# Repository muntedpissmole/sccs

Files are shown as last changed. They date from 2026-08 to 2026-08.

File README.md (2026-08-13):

<h1>
  SCCS
  The Singularity Camper Control System
</h1>

The SCCS is a control system for the electrics in your caravan or camper trailer. It replaces a switch panel and battery/water gauges etc. with a modern touchscreen UI that provides:
- Automated control of lighting based on sunset/sunrise times and door/panel open and closes.
- Display of important information:
  - Battery level and usage
  - Solar generation
  - Water tank levels
  - Location data
  - outside/fridge temperature and weather forecasts
  - Sonos speakers

The system is made up of a Raspberry Pi and custom PCB, the SCCS Core that is the central hub where all field wiring connects to.

The SCCS software configures the Raspberry Pi as a router so that Internet can be distributed from a USB/Wi-Fi hotspot or Starlink through a downstream WAP, enabling a local Wi-Fi network that gives your devices access to the UI and provides ad-filtered Internet access.

Networking services - NAT, DNS, DHCP and ad-filtering are provided by nftables and Pi-Hole, which are automatically configured during installation. Instructions are provided for installing the UniFi OS server for management of UniFi WAP points if desired. Apple HomeKit and Google Home can be configured to enable voice commands of lighting through Siri or Gemini. Cloudflare Tunnels is supported for remote access to the system while away from the caravan/camper.

An interactive demo is available at [demo.singularityautomation.com.au](https://demo.singularityautomation.com.au).

## Getting started

## Quickstart

1. Order SCCS Core PCB from JLCPCB by uploading the contents of the `/kicad/production` folder to JLCPCB. Get PCBA (assembly) done as well - you will receive a warning during the component placement stage that the same component is mapped to multiple parts. This is intentional, tick the checkboxes to include them in the build and continue.
2. Install wiring and SCCS core.
3. Install the software with the install command:

```bash
curl -fsSL https://raw.githubusercontent.com/muntedpissmole/sccs/main/install.sh -o /tmp/sccs-install.sh && sudo bash /tmp/sccs-install.sh
```

Full instructions are in the [project wiki](https://github.com/muntedpissmole/sccs/wiki/).

## System overview

A touchscreen in the kitchen or similar area shows the main user interface and is also reachable from phones or tablets on the LAN:

- Dimmable lighting sliders with red/white anti-bug mode and on/off buttons for non-dimmable loads (water, lighting, fridge circuits)
- Ambient lights that fade on as it gets dark
- One-touch lighting scenes
- Control of Sonos speakers
- Light/dark UI themes and an extensive settings page
- Integration with Apple HomeKit and Google Home

## Display of Environmental information

- Water tank level
- Current temperature and fridge/freezer temperatures
- Current battery charge, voltage, current consumption, estimated power remaining and current/daily solar generation
- GPS coordinates, closest suburb, altitude, satellite quality, sunrise/sunset, and the day/evening/night timing that drives automation
- 4 Day weather forecast, humidity and expected overnight temperature if Internet is present
- Internet connection quality details
- What lights are on and what doors or panels are open
- Health status of connected hardware modules like solar or GPS

## Hardware architecture

- Raspberry Pi 4/5
- Dual ESP32-S3s for 16 channels of PWM dimming via MOSFETs
- u-blox NEO-M9N GPS for location data
- Victron SmartShunt and SmartSolar support for battery and solar monitoring
- WS281X addressable LED strip outputs
- 10A relays for non-dimmable loads like lighting circuits, floodlights and water pumps
- Reed switch inputs for door/panel sensing and triggering of lights
- 1-Wire bus for temperature sensors
- Water tank level sensor input
- Spare channels for everything for expansion

## Hardware and User Interface

### SCCS Core

<table>
  <tr>
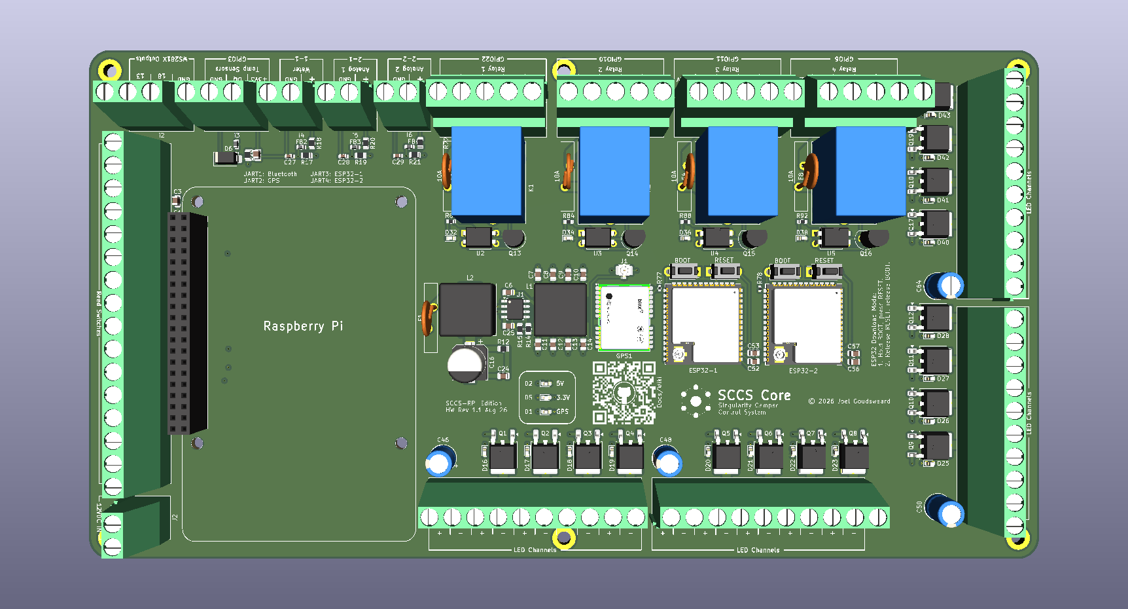
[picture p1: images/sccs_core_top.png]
SCCS Core — top, bare board
    <td align="center" width="50%"></td>
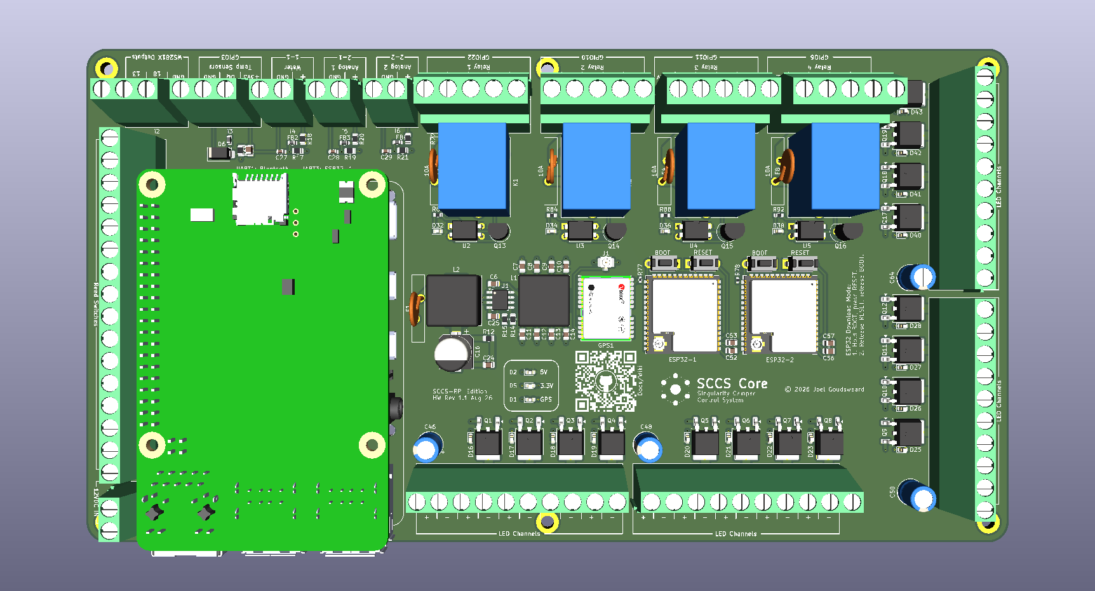
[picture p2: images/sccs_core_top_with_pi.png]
SCCS Core — top, with Raspberry Pi fitted
    <td align="center" width="50%"></td>
  </tr>
  <tr>
    <td align="center"><strong>Top (bare board)</strong></td>
    <td align="center"><strong>Top (with Raspberry Pi fitted)</strong></td>
  </tr>
  <tr>
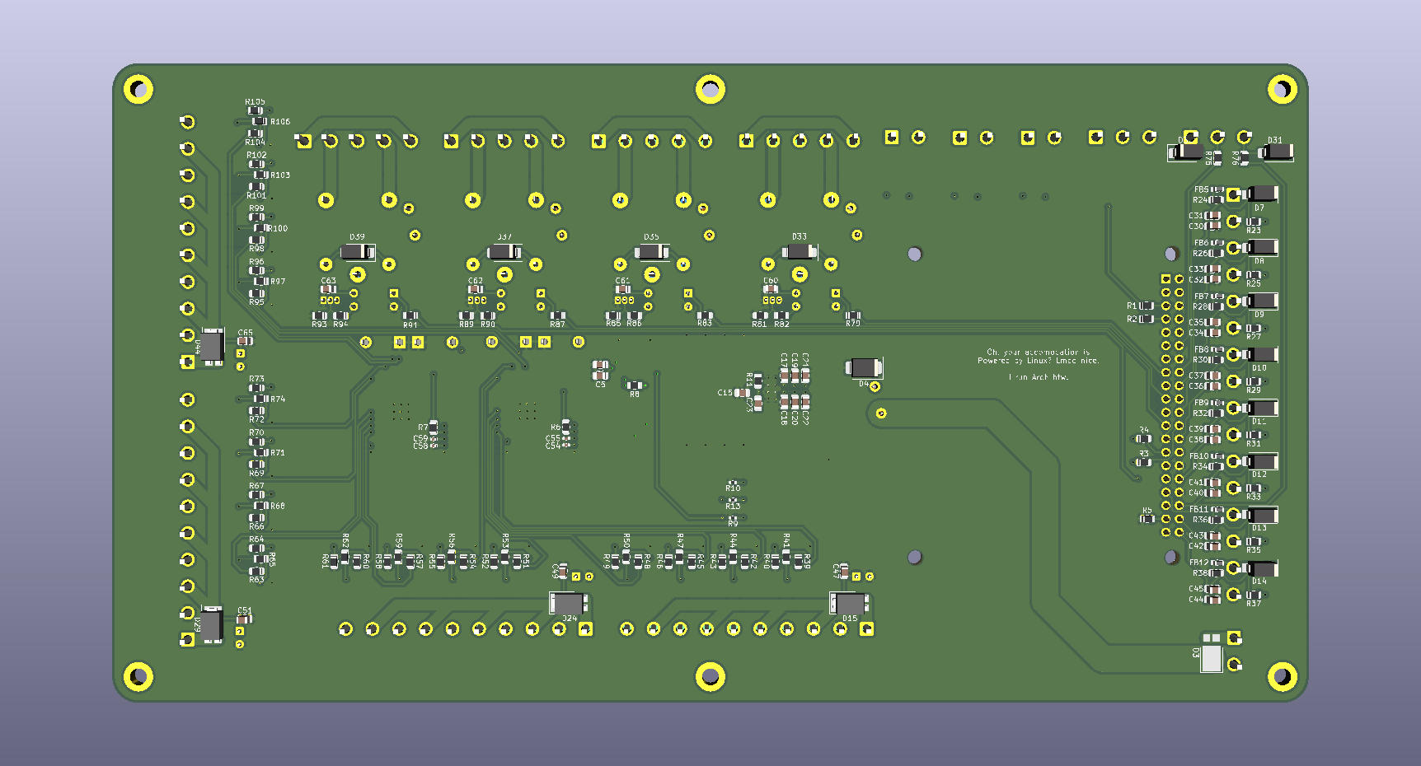
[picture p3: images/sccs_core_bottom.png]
SCCS Core — bottom
    <td align="center"></td>
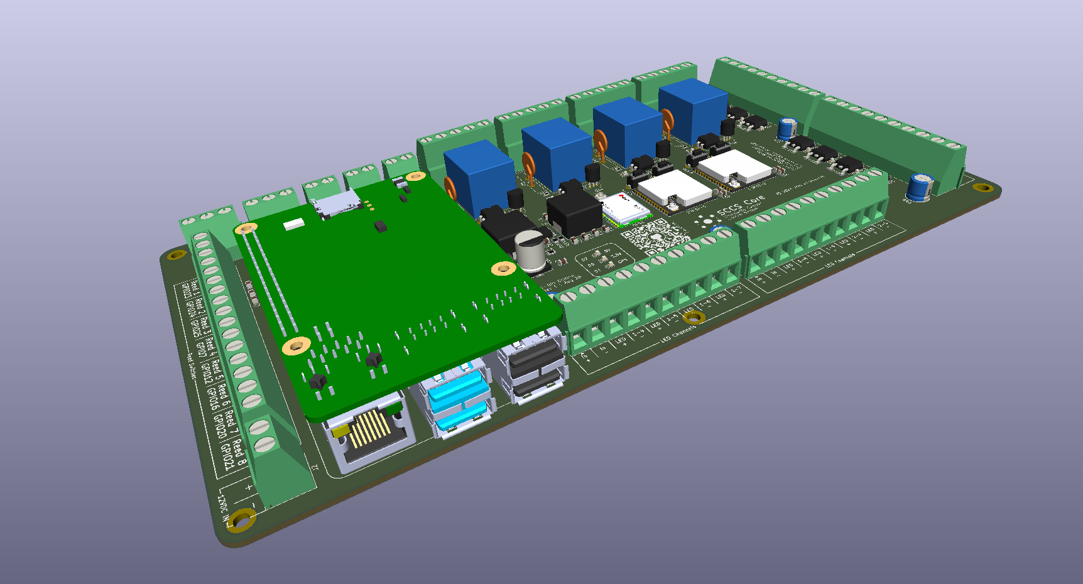
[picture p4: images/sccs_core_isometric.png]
SCCS Core — isometric view with Raspberry Pi fitted
    <td align="center"></td>
  </tr>
  <tr>
    <td align="center"><strong>Bottom</strong></td>
    <td align="center"><strong>Isometric (with Raspberry Pi fitted)</strong></td>
  </tr>
</table>

### 3D Printable Mount

<table>
  <tr>
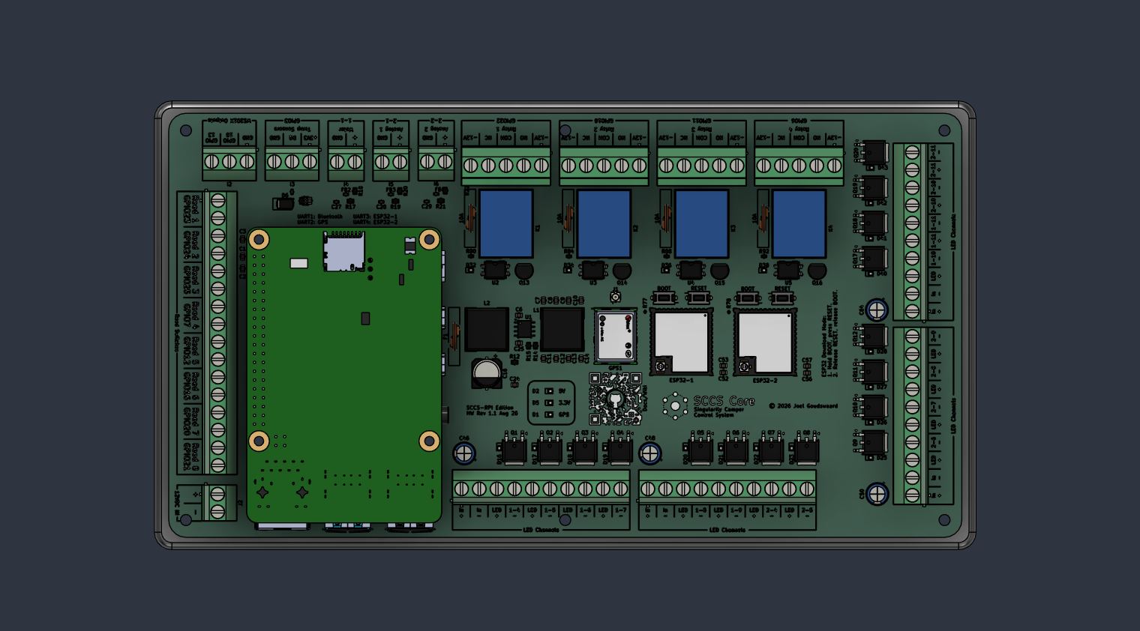
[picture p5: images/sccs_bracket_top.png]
SCCS Core — 3D printable frame, top
    <td align="center" width="50%"></td>
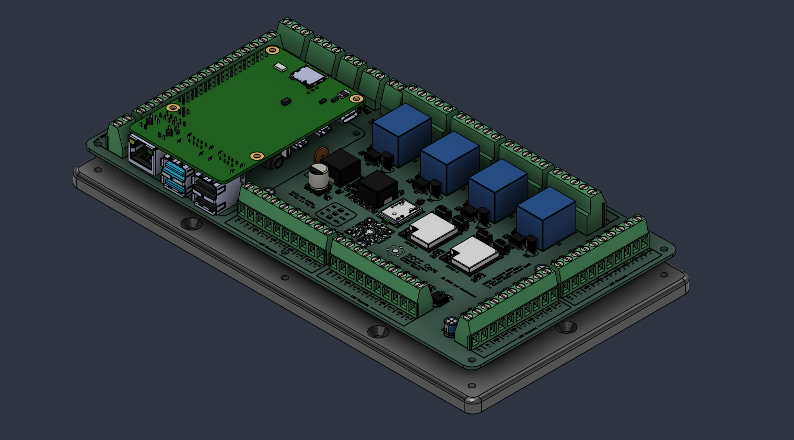
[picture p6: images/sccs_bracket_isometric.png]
SCCS Core — 3D printable frame, isometric
    <td align="center" width="50%"></td>
  </tr>
  <tr>
    <td align="center"><strong>3D printable frame (top)</strong></td>
    <td align="center"><strong>3D printable frame (isometric)</strong></td>
  </tr>
</table>

### User Interface

<table>
  <tr>
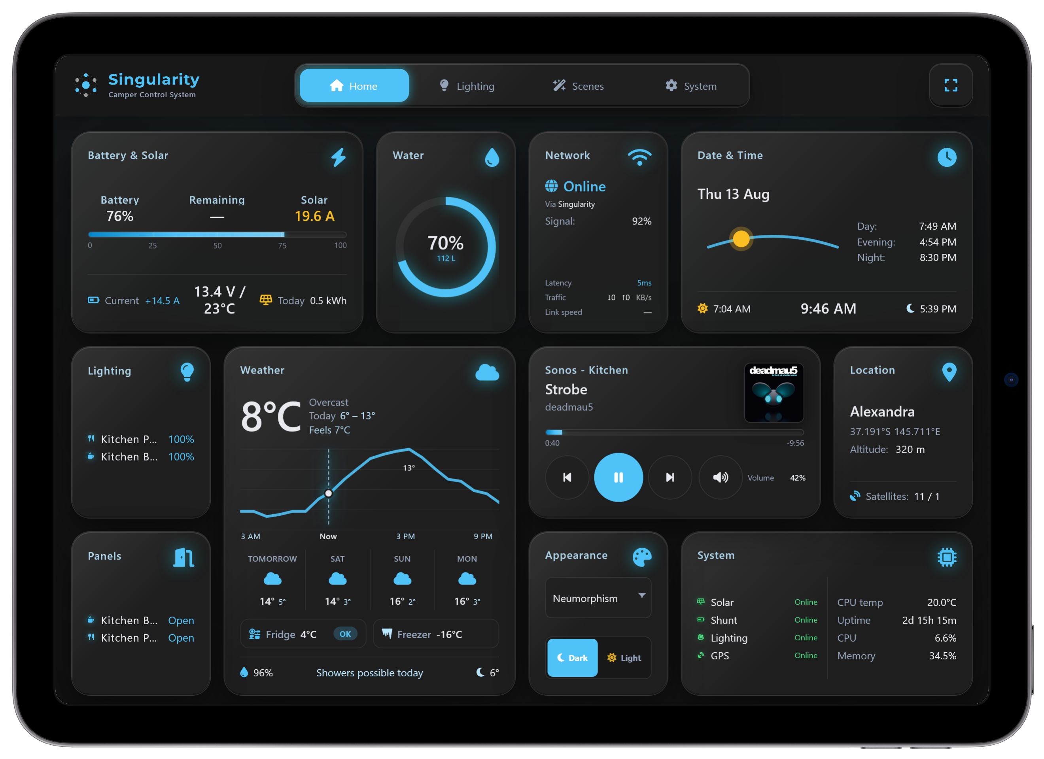
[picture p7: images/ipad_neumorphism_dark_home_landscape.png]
Neumorphism dark — iPad landscape
    <td align="center" width="50%"></td>
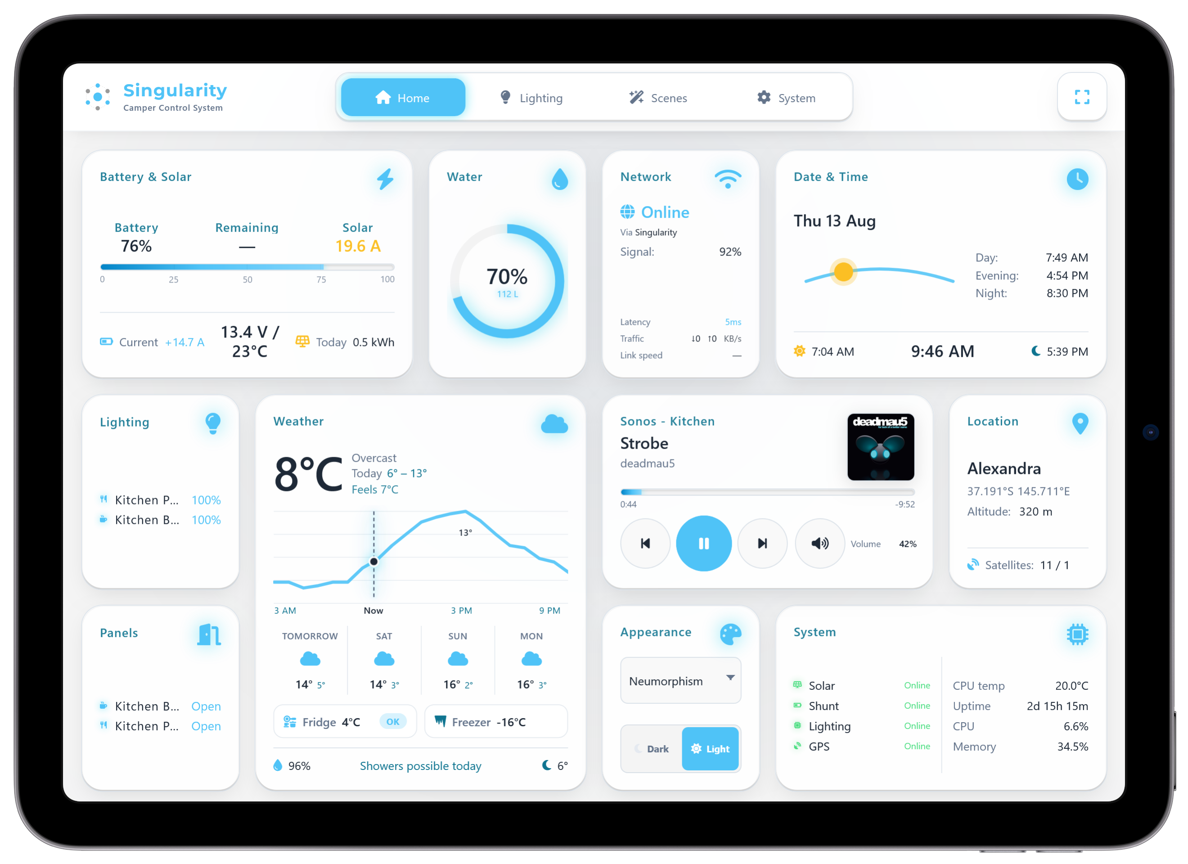
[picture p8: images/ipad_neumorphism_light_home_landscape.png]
Neumorphism light — iPad landscape
    <td align="center" width="50%"></td>
  </tr>
  <tr>
    <td align="center"><strong>Neumorphism (Dark) — iPad</strong></td>
    <td align="center"><strong>Neumorphism (Light) — iPad</strong></td>
  </tr>
  <tr>
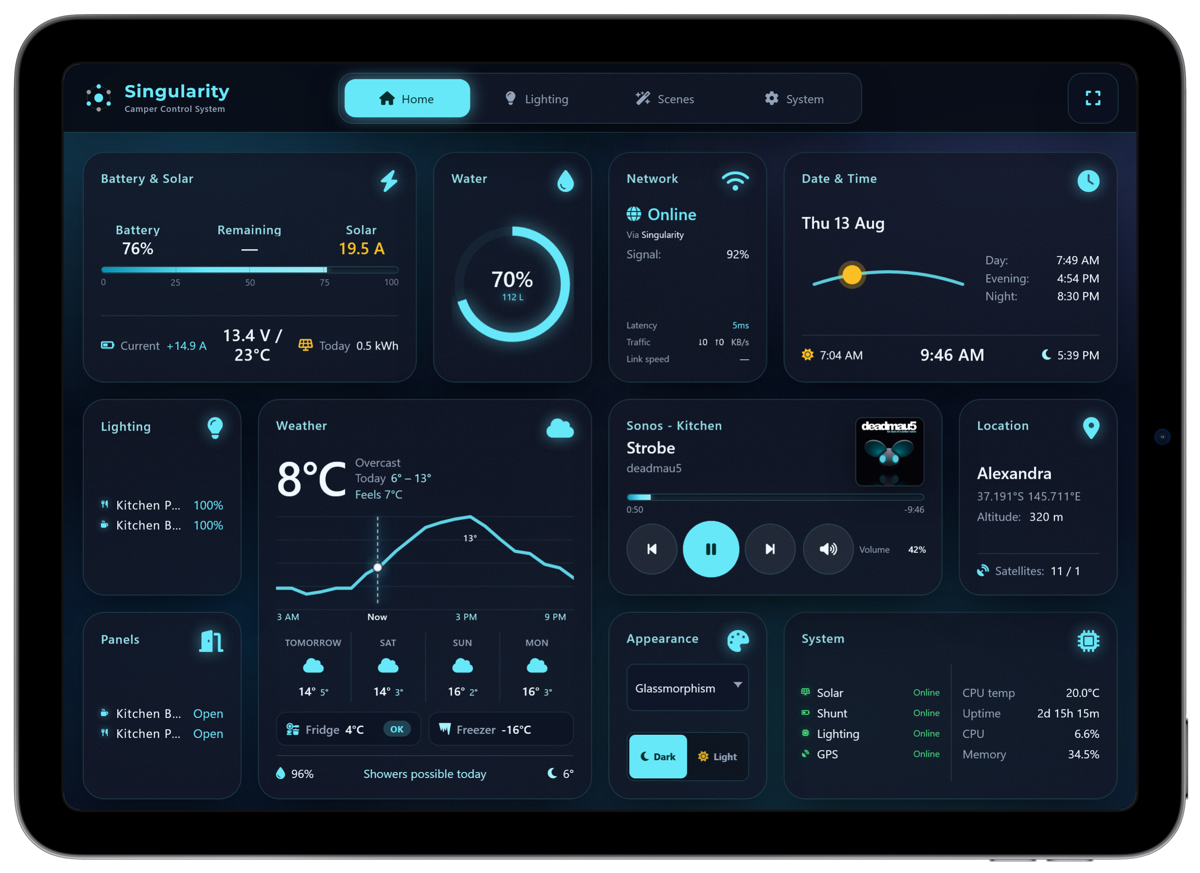
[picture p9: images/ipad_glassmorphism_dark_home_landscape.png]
Glassmorphism dark — iPad landscape
    <td align="center"></td>
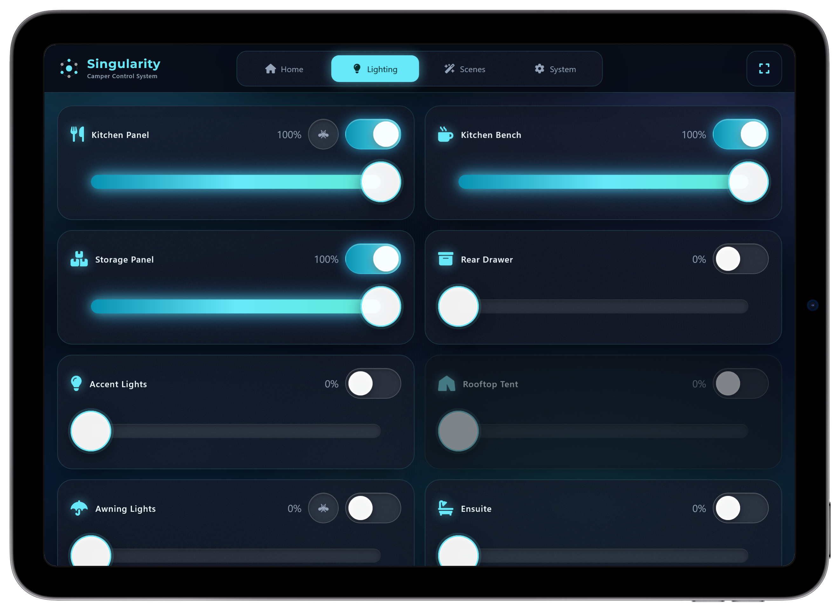
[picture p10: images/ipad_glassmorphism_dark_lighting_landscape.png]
Glassmorphism dark — iPad lighting
    <td align="center"></td>
  </tr>
  <tr>
    <td align="center"><strong>Glassmorphism (Dark) — iPad</strong></td>
    <td align="center"><strong>Glassmorphism (Dark) — iPad Lighting</strong></td>
  </tr>
  <tr>
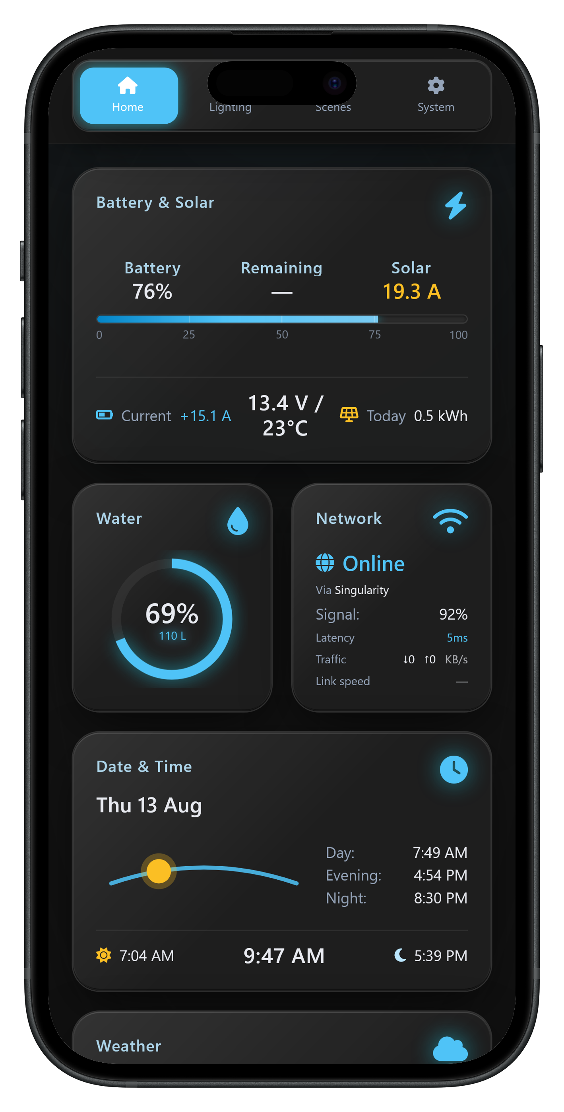
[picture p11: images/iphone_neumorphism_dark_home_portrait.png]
Neumorphism dark — iPhone portrait
    <td align="center"></td>
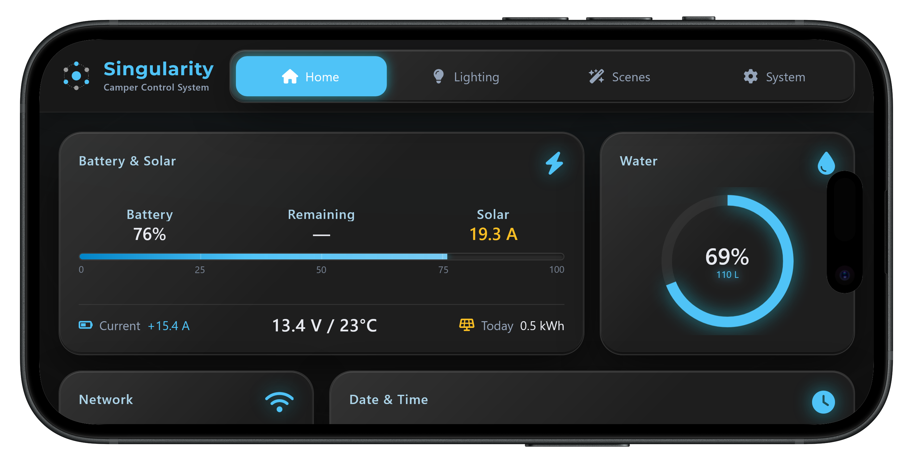
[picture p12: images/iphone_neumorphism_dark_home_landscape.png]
Neumorphism dark — iPhone landscape
    <td align="center"></td>
  </tr>
  <tr>
    <td align="center"><strong>Neumorphism (Dark) — iPhone Portrait</strong></td>
    <td align="center"><strong>Neumorphism (Dark) — iPhone Landscape</strong></td>
  </tr>
</table>

---

## Documentation

Wiring, installation, configuration, and optional packages are on the **[project wiki](https://github.com/muntedpissmole/sccs/wiki)** (start at [Home](https://github.com/muntedpissmole/sccs/wiki/Home) for the setup path and glossary).

| Topic | Wiki page |
|---|---|
| Overview, setup path, glossary | [Home](https://github.com/muntedpissmole/sccs/wiki/Home) |
| Shopping list and wiring | [Wiring and Hardware](https://github.com/muntedpissmole/sccs/wiki/Wiring-and-Hardware) |
| Imaging the Pi and installer | [Software Installation](https://github.com/muntedpissmole/sccs/wiki/Software-Installation) |
| `sccs.conf`, phases, lights, sensors | [Software Configuration](https://github.com/muntedpissmole/sccs/wiki/Software-Configuration) |
| SmartShunt / SmartSolar Bluetooth | [Victron Setup](https://github.com/muntedpissmole/sccs/wiki/Victron-Setup) |
| Apple Home app / Siri (optional) | [HomeKit](https://github.com/muntedpissmole/sccs/wiki/HomeKit) |
| Google Home / Gemini (optional) | [Google Home](https://github.com/muntedpissmole/sccs/wiki/Google-Home) |
| LAN, NAT, Pi-hole, USB internet | [Networking](https://github.com/muntedpissmole/sccs/wiki/Networking) |
| UniFi controller (optional) | [UniFi OS Server](https://github.com/muntedpissmole/sccs/wiki/UniFi-OS-Server) |

---

## License

Licensed under the [MIT License](LICENSE).

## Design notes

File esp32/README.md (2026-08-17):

# SCCS ESP32-S3 firmware

ESP32-S3-WROOM-1U firmware for the two lighting/analog MCUs.

Host protocol (UART0, 115200 8N1): `SET` / `RAMP` / `GET` / `ANALOG` / `GETVCC` / `GETALL`.

Same UART as the ROM bootloader, so `BOOT`+`RESET` uploads over the Pi host serial port.

| Sketch | Role | Pi UART | ESP host UART | PWM GPIOs | Analog GPIOs |
|---|---|---|---|---|---|
| `esp32_1/` | ESP32-1 | `/dev/ttyAMA2` (Pi GPIO 4/5) | GPIO 44 RX / 43 TX (U0) | 4–11 | 1 (water) |
| `esp32_2/` | ESP32-2 | `/dev/ttyAMA3` (Pi GPIO 8/9) | GPIO 44 RX / 43 TX (U0) | 4–11 | 1, 2 |

Shared core: `SccsEspFirmware.h` (copied into each sketch folder).

## Build / flash

- Chip: **ESP32-S3** / **ESP32-S3-WROOM-1U**
- Upload over the Pi host UART (U0). Stop `sccs` first so the port is free.
- Hold BOOT, tap RESET, release BOOT, then upload. Tap RESET again to run.

```bash
arduino-cli core update-index
arduino-cli core install esp32:esp32

arduino-cli compile --fqbn esp32:esp32:esp32s3 esp32/esp32_1
arduino-cli upload -p /dev/ttyAMA2 --fqbn esp32:esp32:esp32s3 esp32/esp32_1

arduino-cli compile --fqbn esp32:esp32:esp32s3 esp32/esp32_2
arduino-cli upload -p /dev/ttyAMA3 --fqbn esp32:esp32:esp32s3 esp32/esp32_2
```

## ADC / water level

- 12-bit reads (0–4095), 64-sample average — matches `water_adc_max = 4095` on the Pi
- `GETVCC` returns `3300` (mV of the 3V3 rail for the 150 Ω pull-ups)
- Water sender on ESP32-1 GPIO 1: empty ~240 Ω, full ~33 Ω (`config/sccs.conf` `[sensors]`)

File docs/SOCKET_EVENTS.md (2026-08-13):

# SCCS Socket Event Contract

This document defines every Socket.IO event used by the lighting backend in this pass.

## Offline overlay

When Socket.IO disconnects (or fails to load), `#offline-overlay` appears after 800ms and blocks interaction until reconnect. Implemented in `offline-overlay.js` + `socket-client.js`.

## Client → Server

### `light_change`

User moved a dimmer slider or toggled a dimmer pill.

```json
{ "name": "kitchen_bench", "brightness": 65 }
```

RGB bug lights include mode:

```json
{ "name": "kitchen_panel", "brightness": 55, "mode": "red" }
```

- `name` must be in `compiled.light_names`
- `brightness` clamped 0–100 server-side
- `mode` only applied for RGB lights

**HTTP fallback:** `POST /api/light` with the same JSON body.

### `relay_change`

User toggled a relay control (socket only — no HTTP fallback).

```json
{ "name": "floodlights", "on": true }
```

Relays use `expires: manual` — they persist through scenes, reed changes, and phase changes until toggled again.

### `get_reeds`

Request effective reed states. Server replies with `reed_update`.

### `set_scene`

Activate a lighting scene (one-shot reconcile with ramp).

```json
{ "scene": "bedtime" }
```

**HTTP fallback:** `POST /api/scene` with the same JSON body.

### `force_phase`

Lock or clear phase override.

```json
{ "phase": "Evening" }
```

Clear: `{ "phase": null }`

### `force_reed`

Diagnostics override (also affects main UI effective states).

```json
{ "name": "rooftop_tent", "closed": true }
```

Clear force: `{ "name": "rooftop_tent", "closed": null }`

## Server → Client

### `lights_config`

Sent on `connect`. Ordered list of UI controls from `sccs.conf`:

```json
[
  { "name": "rooftop_tent", "label": "Rooftop Tent", "type": "dimmer", "icon": "fa-tent", "has_mode": false, "order": 10 }
]
```

`type` is `dimmer` or `relay`.

### `state_update`

Authoritative light/relay levels after reconcile.

```json
{
  "kitchen_bench": 65,
  "kitchen_panel": 55,
  "kitchen_panel_mode": "white",
  "floodlights": 1
}
```

- Dimmers: 0–100 integer brightness
- Relays: truthy/falsey on state
- RGB lights: `{name}_mode` key with `white` or `red`

### `reeds_config`

Sent on `connect`. Reed metadata for the system tile:

```json
[{ "name": "kitchen_panel", "label": "Kitchen Panel", "icon": "fa-utensils", "order": 10 }]
```

### `reed_update` (main UI)

Effective reed states — hardware merged with operator forces.

```json
{ "states": { "rooftop_tent": true, "kitchen_bench": false } }
```

`true` = closed (secure), `false` = open.

**Main UI rule:** clients must not guess forced vs raw. Use this event only.

### `reed_diag_update` (diagnostics — future tile)

Raw hardware + force metadata. Not consumed by the lighting tab yet.

```json
{
  "states": { "rooftop_tent": true },
  "forced": { "kitchen_bench": false }
}
```

### `phase_update` (main UI)

```json
{ "phase": "evening", "day_start": "06:12", "evening_start": "18:45", "night_start": "21:30" }
```

### `gps_update`

Full GPS telemetry from `modules/gps` (also drives home location tile).

```json
{
  "fix_quality": 2,
  "satellites": 9,
  "latitude": -37.191,
  "longitude": 145.711,
  "suburb": "Alexandra",
  "hardware_missing": false
}
```

### `sensor_update`

Water tank and 1-wire temperatures.

```json
{
  "water_percent": 68,
  "outside_temp_c": 12.4,
  "fridge_temp_c": null,
  "temp_valid": true
}
```

### `set_gps_simulation`

Diagnostics: force no-fix mode.

```json
{ "no_fix": true }
```

### `phase_diag_update` (diagnostics)

```json
{ "forced": false }
```

`forced: true` when operator has locked phase via diag controls.

## REST

| Route | Purpose |
|---|---|
| `POST /api/light` | HTTP fallback for `light_change` |
| `GET /api/scenes` | Scene list for Scenes tab |
| `POST /api/scene` | HTTP fallback for `set_scene` |
| `GET /api/reeds` | Reed labels/icons for system tile |
| `GET /api/explain` | Policy snapshot: sources, desired vs observed, drift |

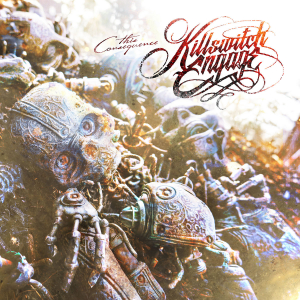
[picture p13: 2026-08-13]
static/images/kse-this-consequence.jpg

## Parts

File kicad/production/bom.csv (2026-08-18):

Designator | Footprint | Quantity | Value | LCSC Part #
C1, C17 | 0805 | 2 | 10uF | C15850
C10, C11, C12, C13, C14, C19, C20, C21, C22, C3, C4, C46, C50, C7, C8, C9 | 0805 | 16 | 22uF | C86816
C15 | 0805 | 1 | 2.7nF | C113859
C16 | CP_Elec_8x10 | 1 | 220uF | C165536
C18, C2, C26, C31, C33, C35, C37, C39, C41, C43, C45, C55, C57, C59, C61, C62, C63, C64, C65 | 0805 | 19 | 100nF | C49678
C23 | 0805 | 1 | 33pF | C541516
C24, C54, C56, C58, C60 | CP_Radial_D6.3mm_P2.50mm | 5 | 100uF | C44587
C25 | 0805 | 1 | 10nF | C237168
C27, C28, C29 | 0603 | 3 | 100nF | C1590
C30, C32, C34, C36, C38, C40, C42, C44 | 0805 | 8 | 1uF | C91185
C47, C5, C51, C6 | 0805 | 4 | 0.1uF | C86041
C48, C49, C52, C53 | 0402 | 4 | 100nF | C60474
D1 | 0603 | 1 | GPS | C2286
D10, D11, D12, D13, D14, D6, D7, D8, D9 | D_SMA | 9 | SMAJ3.3CA | C18199545
D15, D16, D17, D18, D3 | D_PowerDI-5 | 5 | ~ | C2759901
D19, D22, D23, D24, D25, D26, D27, D30, D31, D32, D33, D34 | 0603 | 12 | White | C2290
D2 | 0603 | 1 | 5V | C2286
D20, D28 | 0603 | 2 | Red | C2286
D21, D29 | 0603 | 2 | Green | C12065
D35, D36 | D_SMA | 2 | SMAJ5.0CA | C78402
D37, D39, D41, D43 | 0603 | 4 | Blue | C2288
D38, D40, D42, D44 | D_SMA | 4 | 1N4007 | C64915
D4 | D_SMB | 1 | SMAJ18A/TR13 | C571369
D5 | 0603 | 1 | 3.3V | C2286
ESP32-1, ESP32-2 | ESP32-S3-WROOM-1U | 2 | ESP32-S3-WROOM-1 | C3013946
F1, F2, F3, F4, F5 | Fuse_Bourns_MF-RG1000 | 5 | 10A | C14767
FB1, FB10, FB11, FB12, FB2, FB3, FB4, FB5, FB6, FB7, FB8, FB9 | 0603 | 12 | FerriteBead | C1002
GPS1 | ublox_NEO | 1 | NEO-M9N-00B | C5119087
I1 | TerminalBlock_Phoenix_MKDS-1,5-16-5.08_1x16_P5.08mm_Horizontal | 1 | Reed Switches | C508906
I2 | TerminalBlock_Phoenix_MKDS-1,5-3-5.08_1x03_P5.08mm_Horizontal | 1 | WS281X Outputs | C8412
I3 | TerminalBlock_Phoenix_MKDS-1,5-3-5.08_1x03_P5.08mm_Horizontal | 1 | Temp Sensors | C8412
I4 | TerminalBlock_Phoenix_MKDS-1,5-2-5.08_1x02_P5.08mm_Horizontal | 1 | Water | C8445
I5 | TerminalBlock_Phoenix_MKDS-1,5-2-5.08_1x02_P5.08mm_Horizontal | 1 | Analog 1 | C8445
I6 | TerminalBlock_Phoenix_MKDS-1,5-2-5.08_1x02_P5.08mm_Horizontal | 1 | Analog 2 | C8445
J1 | SMA_Amphenol_132134-11_Vertical | 1 | Conn_Coaxial | C20415804
J2 | TerminalBlock_Phoenix_MKDS-1,5-2-5.08_1x02_P5.08mm_Horizontal | 1 | 12VDC IN | C8445
K1, K2, K3, K4 | Relay_SPDT_SANYOU_SRD_Series_Form_C | 4 | Relay_SPDT | C35449
L1, L2 | L_SXN_SMDRI127 | 2 | 3.3uH | C24550
PI1 | PinSocket_2x20_P2.54mm_Vertical | 1 | Raspberry PI HAT | C132132
PWM1, PWM2, PWM3, PWM4 | TerminalBlock_Phoenix_MKDS-1,5-10-5.08_1x10_P5.08mm_Horizontal | 4 | LED Channels | C29173
Q1, Q10, Q11, Q12, Q13, Q14, Q15, Q16, Q2, Q3, Q4, Q5, Q6, Q7, Q8, Q9 | TO-252-2 | 16 | IRLB8721PBF | C99124
Q17, Q18, Q19, Q20 | TO-92_Inline | 4 | 2N7000 | C9114
R1, R2, R21, R23, R25, R27, R29, R3, R31, R33, R35, R4, R6, R7, R8 | 0805 | 15 | 220R | C17557
R10, R13, R9 | 0402 | 3 | 1K | C11702
R100, R104, R41, R44, R47, R50, R53, R56, R59, R62, R65, R68, R71, R74, R77, R80, R83, R86, R92, R96 | 0805 | 20 | 10K | C17414
R101, R105, R40, R43, R46, R49, R52, R55, R58, R61, R64, R67, R70, R73, R76, R79, R82, R85, R93, R97 | 0805 | 20 | 100R | C17408
R102, R90, R94, R98 | 0805 | 4 | 330R | C17630
R103, R91, R95, R99 | 0603 | 4 | 1K | C5123612
R11 | 0805 | 1 | 15.8K | C17468
R12 | 0805 | 1 | 1R | C25271
R14 | 0805 | 1 | 115K | C158272
R15 | 0805 | 1 | 22.1K | C17552
R16 | 0805 | 1 | 2.2K | C17520
R17, R18, R19 | 0805 | 3 | 150R | C17471
R20, R22, R24, R26, R28, R30, R32, R34, R5 | 0805 | 9 | 4.7K | C17673
R36, R37, R38, R39 | 0402 | 4 | 10K | C60490
R42, R45, R48, R51, R54, R57, R60, R63, R66, R69, R72, R75, R78, R81, R84, R87 | 0805 | 16 | 1K | C17513
R88, R89 | 0805 | 2 | 33R | C17634
RE1 | TerminalBlock_Phoenix_MKDS-3-5-5.08_1x05_P5.08mm_Horizontal | 1 | Relay 1 | C8423
RE2 | TerminalBlock_Phoenix_MKDS-3-5-5.08_1x05_P5.08mm_Horizontal | 1 | Relay 2 | C8423
RE3 | TerminalBlock_Phoenix_MKDS-3-5-5.08_1x05_P5.08mm_Horizontal | 1 | Relay 3 | C8423
RE4 | TerminalBlock_Phoenix_MKDS-3-5-5.08_1x05_P5.08mm_Horizontal | 1 | Relay 4 | C8423
RP? | raspberrypi_4 | 1 | Raspberry_Pi_2_3
SW1, SW3 | SW_PUSH_1P1T_6x3.5mm_H5.0_APEM_MJTP1250 | 2 | RESET | C500070
SW2, SW4 | SW_PUSH_1P1T_6x3.5mm_H5.0_APEM_MJTP1250 | 2 | BOOT | C500070
U1 | SOIC-8-1EP_3.9x4.9mm_P1.27mm_EP2.95x4.9mm_Mask2.71x3.4mm_ThermalVias | 1 | AP64501SP-13 | C2071517
U2, U3, U4, U5 | DIP-4_W7.62mm | 4 | PC817 | C5353

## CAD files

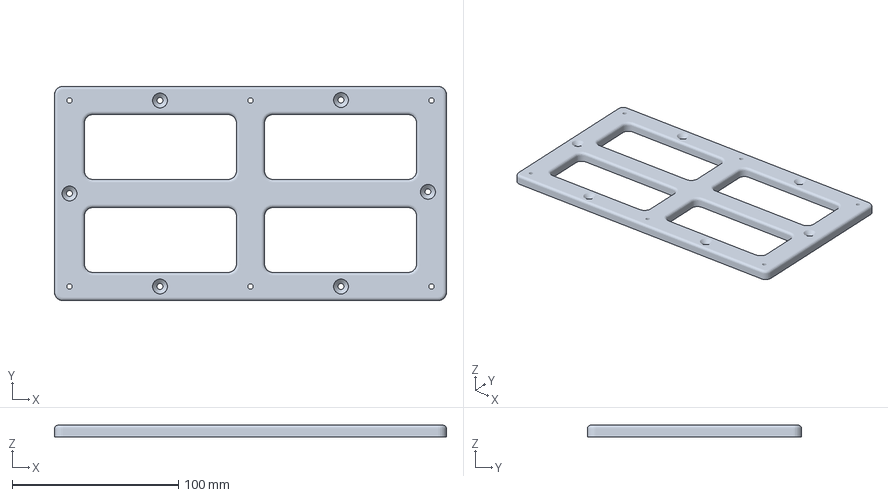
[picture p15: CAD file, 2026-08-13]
kicad/SCCS Mount.3mf
236.1 x 129.0 x 7.00 mm

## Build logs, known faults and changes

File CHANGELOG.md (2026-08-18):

# Changelog

All notable changes to SCCS are documented in this file.

## [1.1.2.18082026] - 2026-08-18

### Added
- Installer 1-Wire setup can delete a temperature sensor role from `sccs.conf`; skip still leaves the existing value

## [1.1.1.18082026] - 2026-08-18

### Fixed
- Startup treated every reed as closed until the poller started, so the first lighting pass and a connecting UI could show “all panels closed”. Reeds are now sampled (three quick GPIO reads) before HTTP is advertised and before any lights or scenes run
- No-fix GPS sentences were stored as 0°N 0°E. Weather then fetched the equator (~24 °C). Empty GGA/RMC is ignored; with no valid fix the Alexandra fallback is used
- pynmea2 raised on void RMC datetime (`$GNRMC,,V,…`); those sentences no longer crash the GPS reader
- Settings tiles with `[hidden]` still painted in WebKit because author `display:flex` beat the UA rule

### Changed
- `[reeds]` comments map i1 pin pairs to functions; kitchen bench is GPIO23 and kitchen panel GPIO24
- Night bathroom scene renamed from `ensuite` to `bathroom`

## [1.1.17082026] - 2026-08-17

### Fixed
- ESP32 lighting stayed offline after a successful flash: the host protocol now uses UART0 (`Serial0` on GPIO 44/43), the same pins as the ROM bootloader, instead of a second `HardwareSerial(0)` on UART1
- Installer flashed over `/dev/ttyACM*` instead of the SCCS Core host UARTs; uploads now target `/dev/ttyAMA2` (ESP32-1) and `/dev/ttyAMA3` (ESP32-2) as the same user that compiled
- A failed `GETVCC` check after upload sent the installer back through the ESP32-1 flash loop. Handshake retries no longer re-flash; the next module is offered after a warning
- `USBMode=default` selected TinyUSB OTG (not the board default) and could hang `setup()` on modules with no USB. The FQBN stays `esp32:esp32:esp32s3`
- Pi UART has no RTS reset line, so esptool cannot start the app. The installer now asks for a RESET tap and checks `GETVCC` before moving on
- `sccs.service` is stopped for the upload and started again when the ESP step ends (including skip, abort, or Ctrl-C)
- Host `GETVCC` probe retries briefly after open so lighting can come online while firmware is still leaving reset

### Changed
- Installer enables the correct UART overlays per board: `uart2`/`uart3`/`uart4` on Pi 4, `uart1-pi5`/`uart2-pi5`/`uart3-pi5` on Pi 5 (GPS `/dev/ttyAMA1`, ESP1 `/dev/ttyAMA2`, ESP2 `/dev/ttyAMA3`)
- Firmware answers the host on a non-blocking line reader and prints `SCCS n READY` as soon as UART0 is up

## [1.0.0.13082026] - 2026-08-13

### Added
- Initial release of the Singularity Camper Control System (SCCS)
- Touchscreen UI for dimmable lighting, scenes, reeds, phases, water, climate, power, GPS, weather and networking
- Optional Apple HomeKit and Google Home control (off by default; installer menu 10 or Settings)
- Installer for imaging, Victron, LAN/Pi-hole, USB tethering and touchscreens

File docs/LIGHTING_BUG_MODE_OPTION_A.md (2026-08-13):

# Lighting bug mode — Option A (separate chip)

**Date:** 2026-06-11  
**Status:** Applied

## Problem

On `rgb_bug` lights (e.g. Kitchen Panel, Awning), the header toggle pill toggled **white ↔ bug (red) mode**, not on/off. Other cards use the same pill for **power**. Same control, different meaning.

## Solution (Option A)

- **Toggle pill** — on/off only (brightness 0 ↔ last brightness), same as PWM dimmers. Still uses `.bug-mode` styling (red) when bug mode is active.
- **Bug mode chip** — new mosquito button left of the pill; toggles `white` ↔ `red` mode only.
- **Slider / card chrome** — still turns red in bug mode (unchanged).

## Files changed

| File | Change |
|---|---|
| `static/js/lighting-controller.js` | Pill logic, `toggleBugMode()`, chip in card HTML, click handler |
| `static/css/components/lighting.css` | `.bug-mode-chip` styles |

## Behaviour before (revert target)

In `lighting-controller.js` → `updateLightUI()`:

```javascript
const pillOn = light.has_mode ? isBugMode : brightness > 0;
pills.forEach((pill) => {
    pill.classList.toggle('on', pillOn);
    pill.classList.toggle('bug-mode', isBugMode);
    ...
});
```

In `toggleControl()`:

```javascript
if (light.has_mode) {
    const newMode = currentMode === 'white' ? 'red' : 'white';
    // ... mode toggle only, no brightness change
    return;
}
```

Card HTML used `colour-toggle` class on the pill; no bug chip.

## How to revert

1. Delete `.bug-mode-chip` rules from `lighting.css`.
2. In `lighting-controller.js`:
   - Restore `pillOn = light.has_mode ? isBugMode : brightness > 0`.
   - Restore `bug-mode` class on pills in `updateLightUI()`.
   - Restore `if (light.has_mode) { ... mode toggle ... return; }` in `toggleControl()`.
   - Remove `toggleBugMode()` and bug-chip branch in `handleLightingClick`.
   - Remove bug chip from card HTML; restore `colour-toggle` on pill for `has_mode` lights.
3. Delete this doc if no longer needed.

## Unchanged

- Socket/API: `light_change` still sends `{ name, brightness, mode }`.
- Home tile bug indicator (`is-bug-mode` when `mode === 'red'`).
- Scenes / `*_mode` keys in state.
- Slider `.bug-mode` fill/thumb styling.

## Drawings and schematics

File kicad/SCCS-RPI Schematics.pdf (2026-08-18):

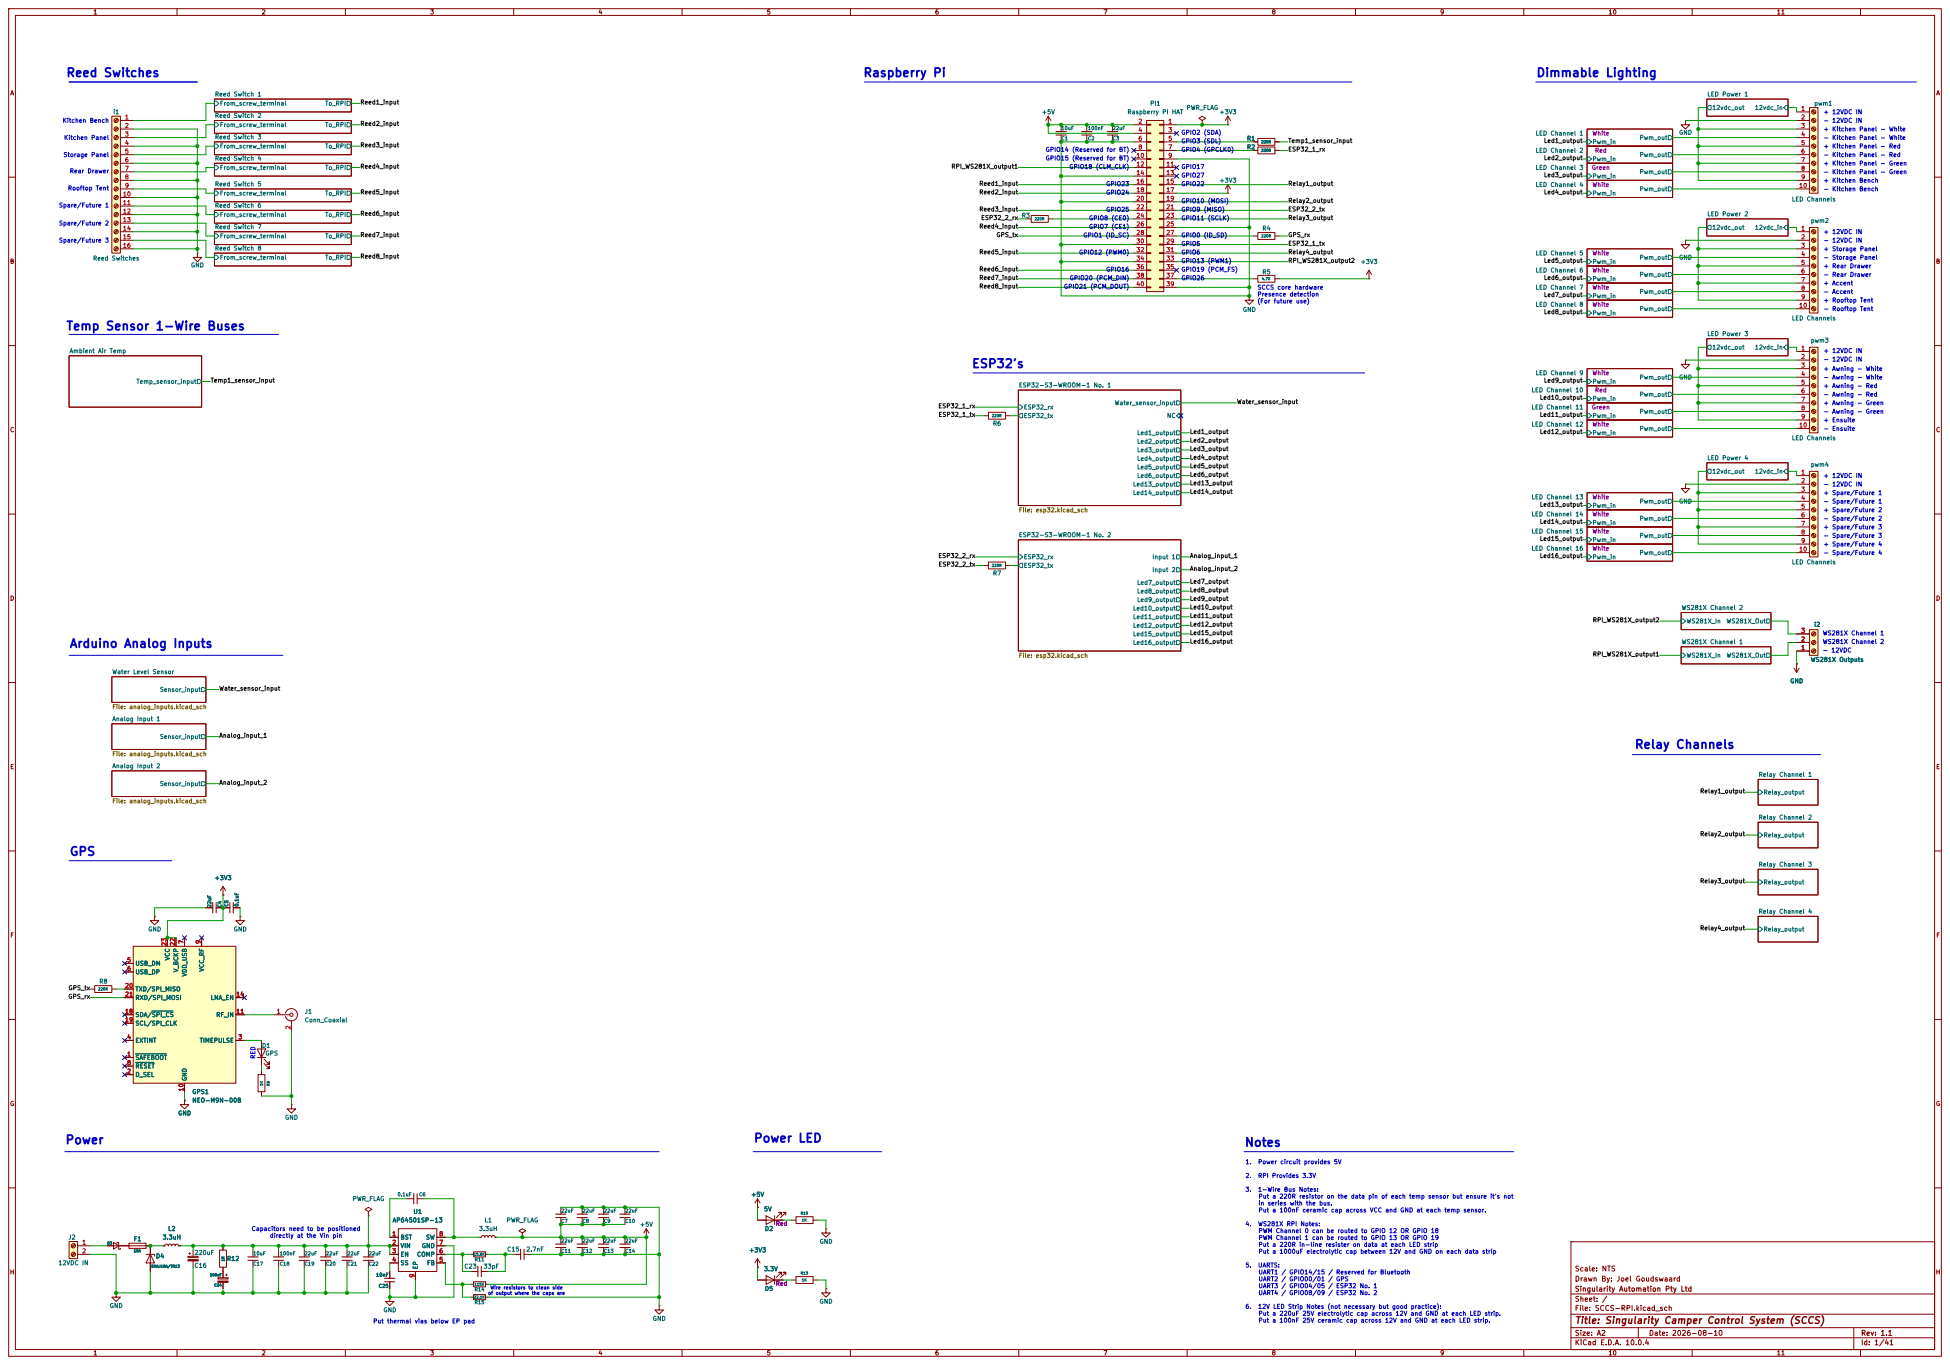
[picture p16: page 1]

Storage Panel Spare/Future 1

Spare/Future 3 Temp Sensor 1-Wire Buses

SCCS core hardware Presence detection

+ 12VDC IN + Ensuite - 12VDC IN - Awning - Green - Ensuite

+ Spare/Future 2 + Spare/Future 4

1. Power circuit provides 5V 2. RPI Provides 3.3V 3. 1-Wire Bus Notes: Put a 220R resistor on the data pin of each temp sensor but ensure it's not

in series with the bus. Put a 100nF ceramic cap across VCC and GND at each temp sensor. 4. WS281X RPI Notes: PWM Channel 0 can be routed to GPIO 12 OR GPIO 18 PWM Channel 1 can be routed to GPIO 13 OR GPIO 19 Put a 220R in-line resister on data at each LED strip Put a 1000uF electrolytic cap between 12V and GND on each data strip 5. UARTS: UART1 / GPIO14/15 / Reserved for Bluetooth UART2 / GPIO00/01 / GPS UART3 / GPIO04/05 / ESP32 No. 1 UART4 / GPIO08/09 / ESP32 No. 2

Capacitors need to be positioned
directly at the Vin pin

Scale: NTS
Drawn By: Joel Goudswaard
Singularity Automation Pty Ltd
Sheet: /
File: SCCS-RPI.kicad_sch
Title: Singularity Camper Control System (SCCS)

Wire resistors to clean side of output where the caps are

6. 12V LED Strip Notes (not necessary but good practice): Put a 220uF 25V electrolytic cap across 12V and GND at each LED strip. Put a 100nF 25V ceramic cap across 12V and GND at each LED strip.

Put thermal vias below EP pad

Size: A2 | Rev: 1.1
KiCad E.D.A. 10.0.4 | Id: 1/41

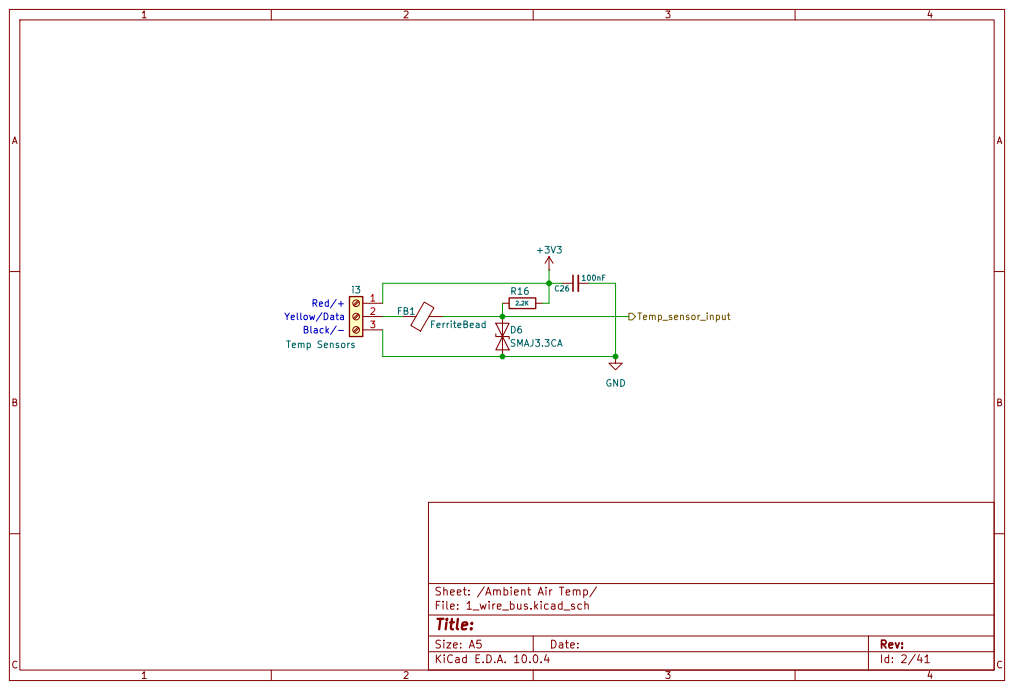
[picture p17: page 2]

Sheet: /Ambient Air Temp/
File: 1_wire_bus.kicad_sch
Title:

Size: A5 | Rev: | C Date:
KiCad E.D.A. 10.0.4 | Id: 2/41

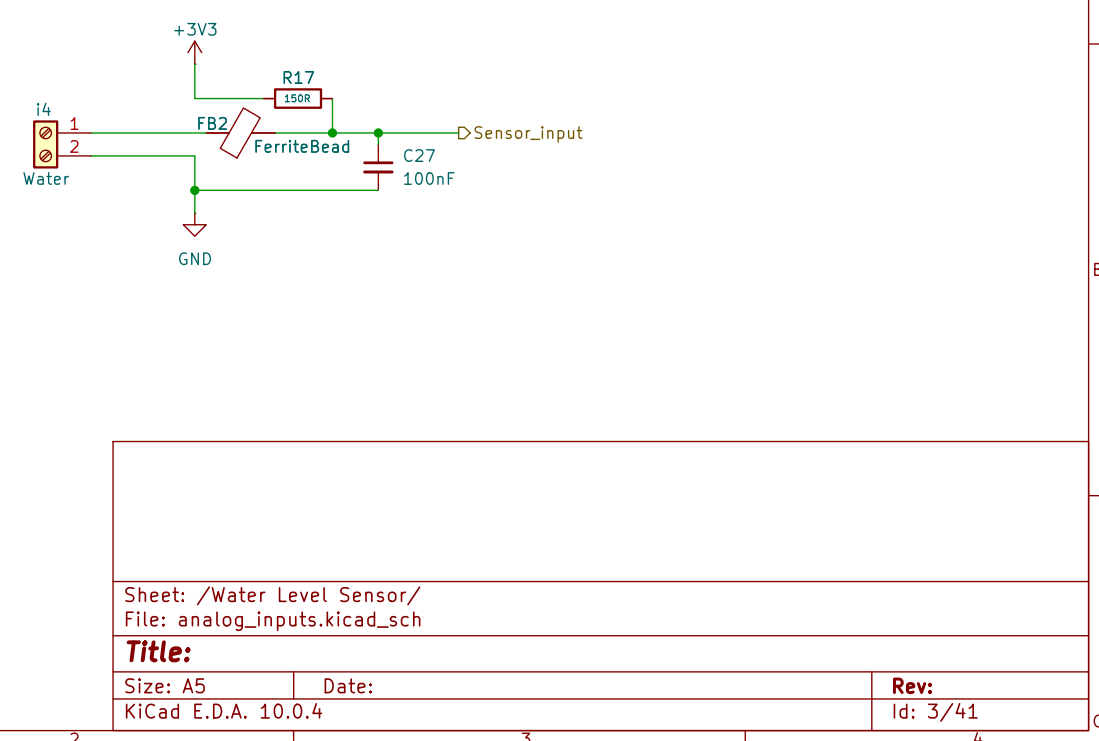
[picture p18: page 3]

Sheet: /Water Level Sensor/
File: analog_inputs.kicad_sch
Title:

Size: A5 | Rev: | C Date:
KiCad E.D.A. 10.0.4 | Id: 3/41

Size: A5 | Rev: | C Date:
KiCad E.D.A. 10.0.4 | Id: 4/41

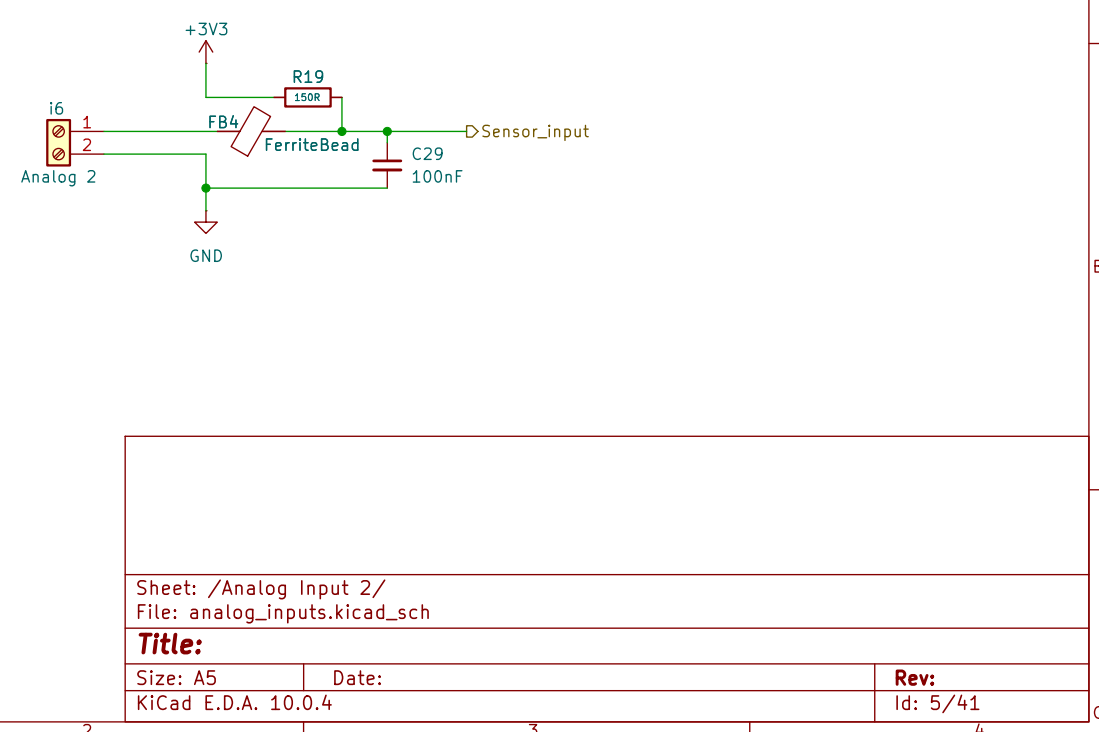
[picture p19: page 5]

Size: A5 | Rev: | C Date:
KiCad E.D.A. 10.0.4 | Id: 5/41

Size: A5 | Rev: | C Date:
KiCad E.D.A. 10.0.4 | Id: 6/41

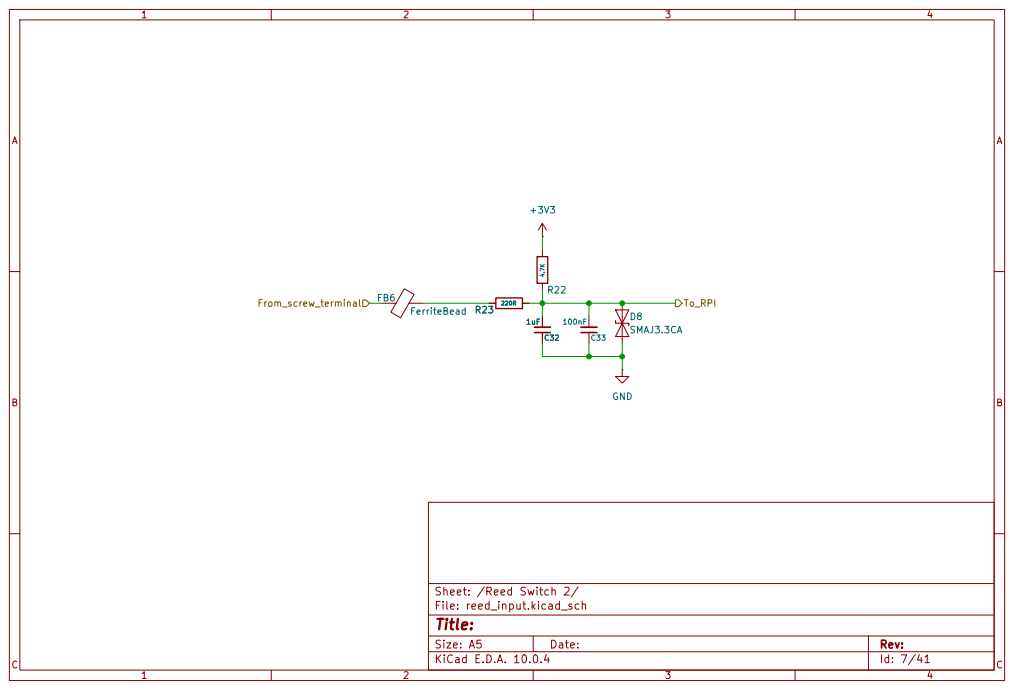
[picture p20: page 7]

Size: A5 | Rev: | C Date:
KiCad E.D.A. 10.0.4 | Id: 7/41

Size: A5 | Rev: | C Date:
KiCad E.D.A. 10.0.4 | Id: 8/41

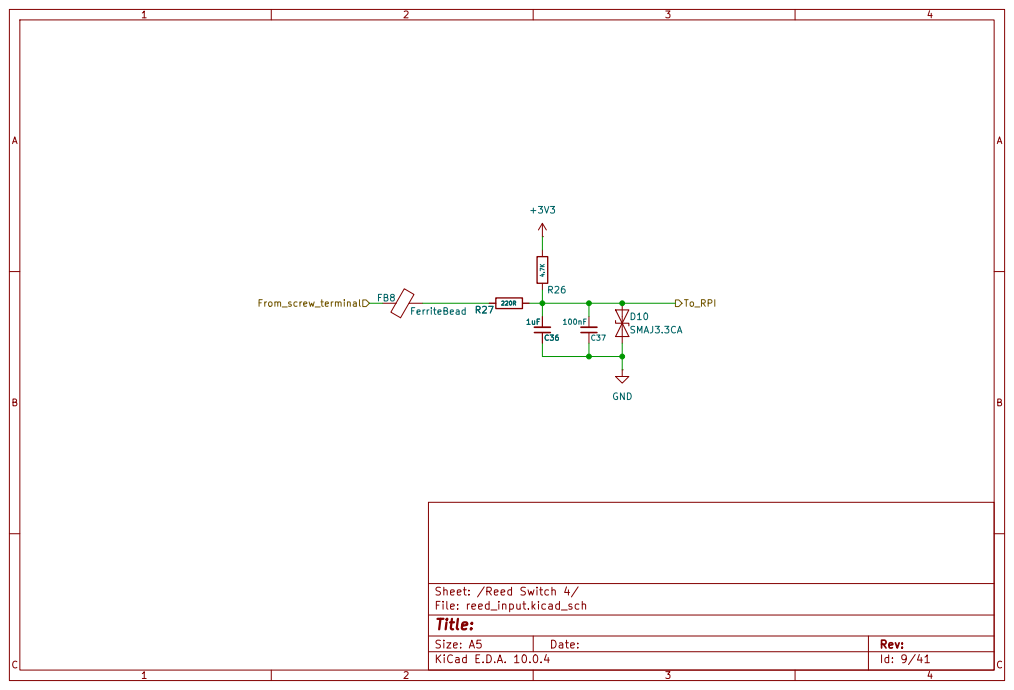
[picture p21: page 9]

Size: A5 | Rev: | C Date:
KiCad E.D.A. 10.0.4 | Id: 9/41

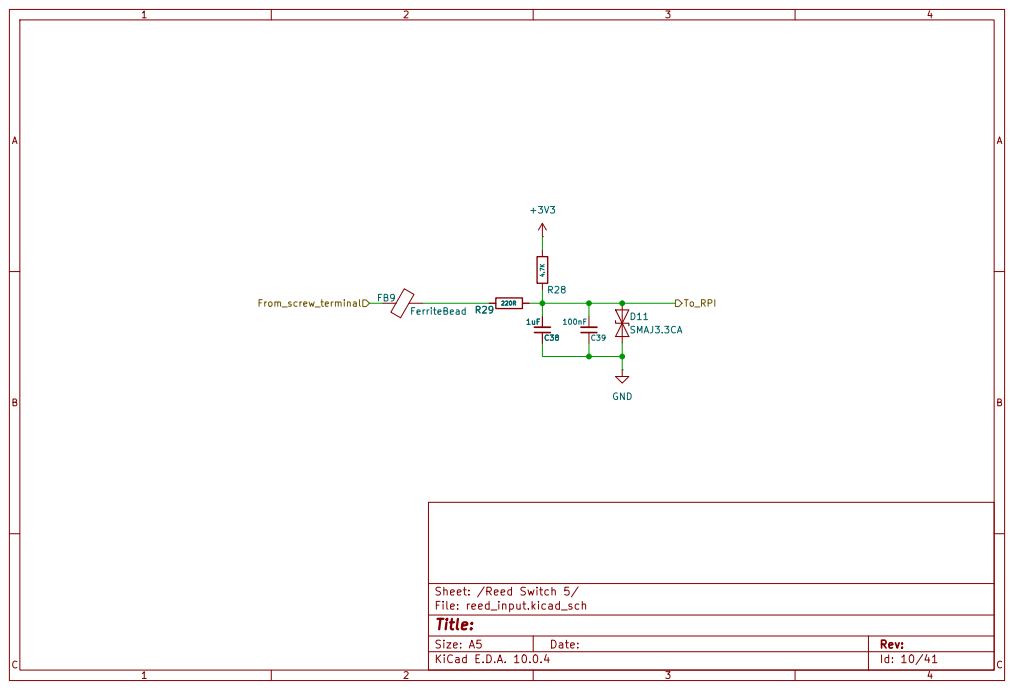
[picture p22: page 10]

Size: A5 | Rev: | C Date:
KiCad E.D.A. 10.0.4 | Id: 10/41

Size: A5 | Rev: | C Date:
KiCad E.D.A. 10.0.4 | Id: 11/41

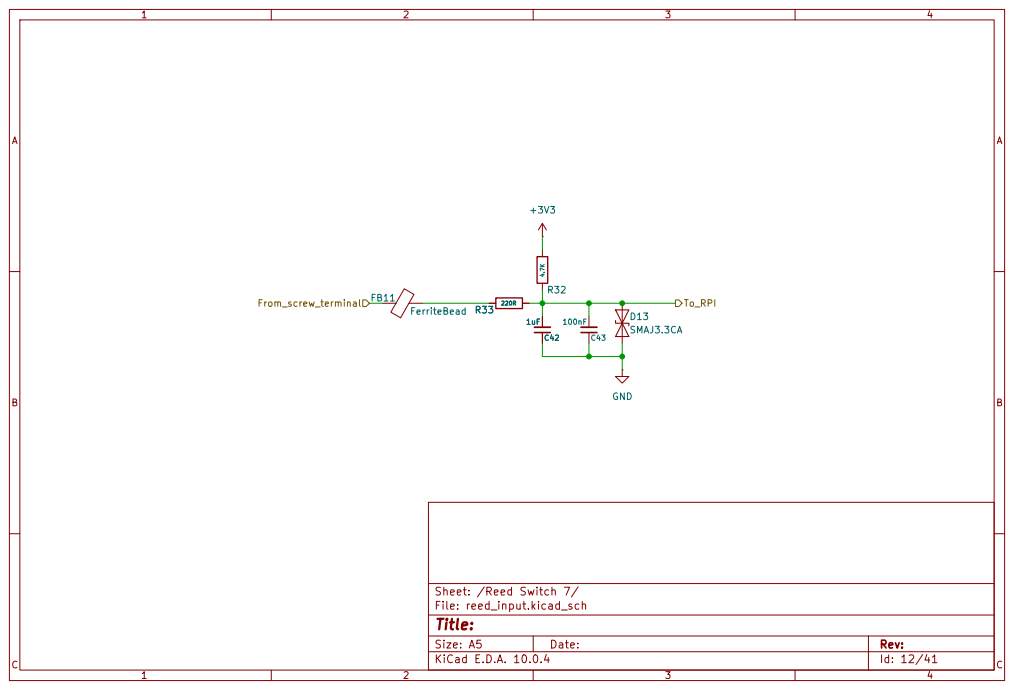
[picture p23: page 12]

Size: A5 | Rev: | C Date:
KiCad E.D.A. 10.0.4 | Id: 12/41

Size: A5 | Rev: | C Date:
KiCad E.D.A. 10.0.4 | Id: 13/41

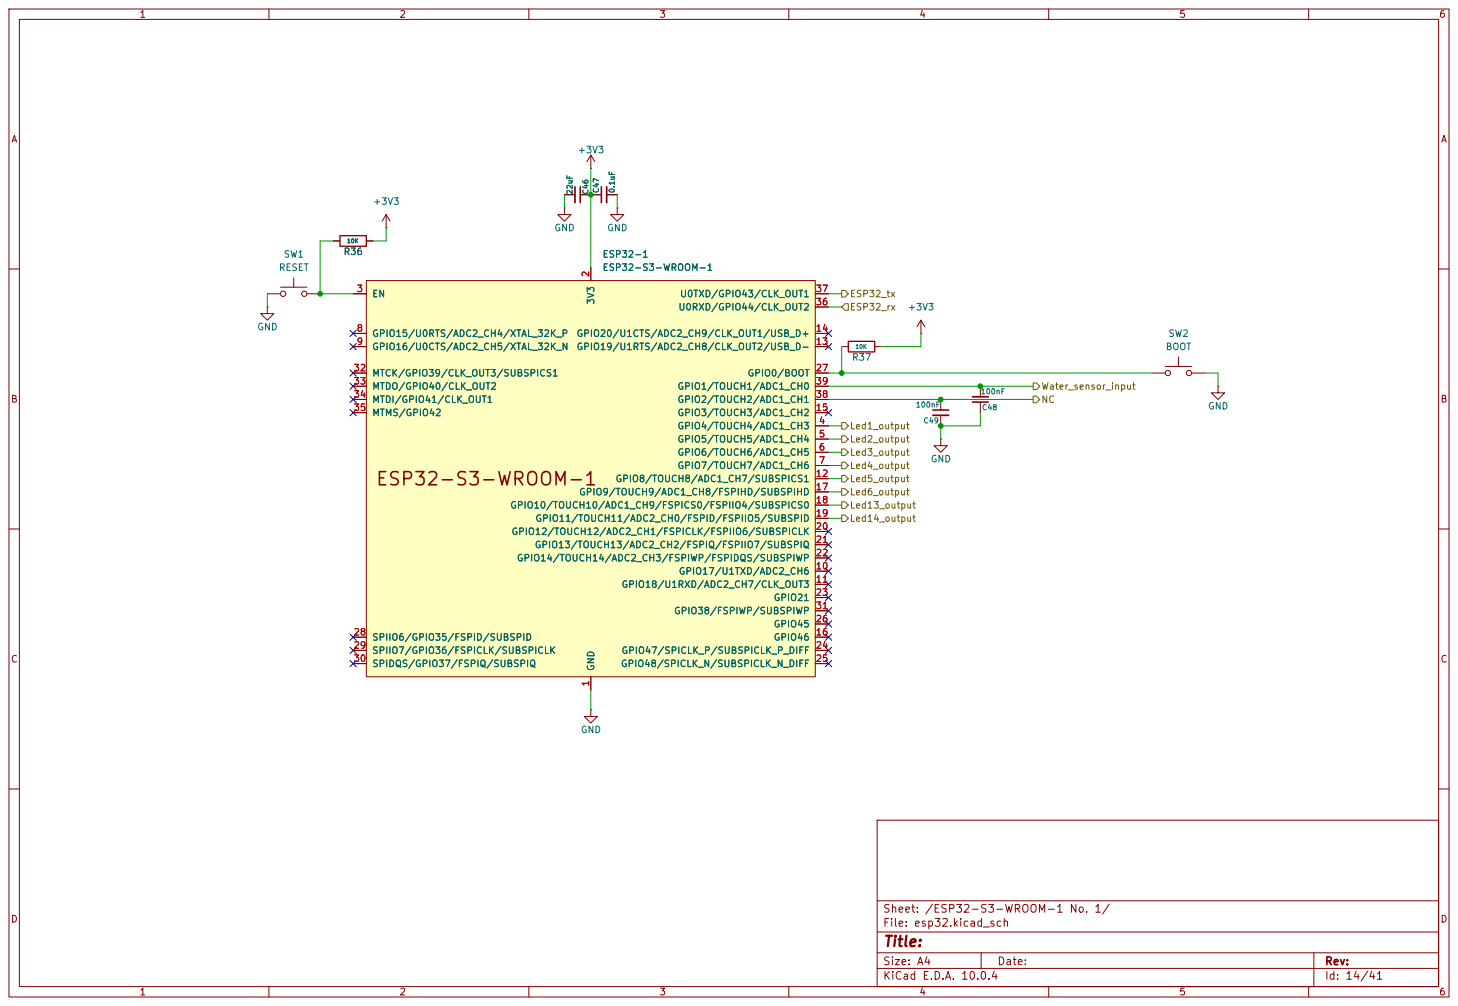
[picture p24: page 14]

Size: A4 | Rev:
KiCad E.D.A. 10.0.4 | Id: 14/41

Size: A4 | Rev:
KiCad E.D.A. 10.0.4 | Id: 15/41

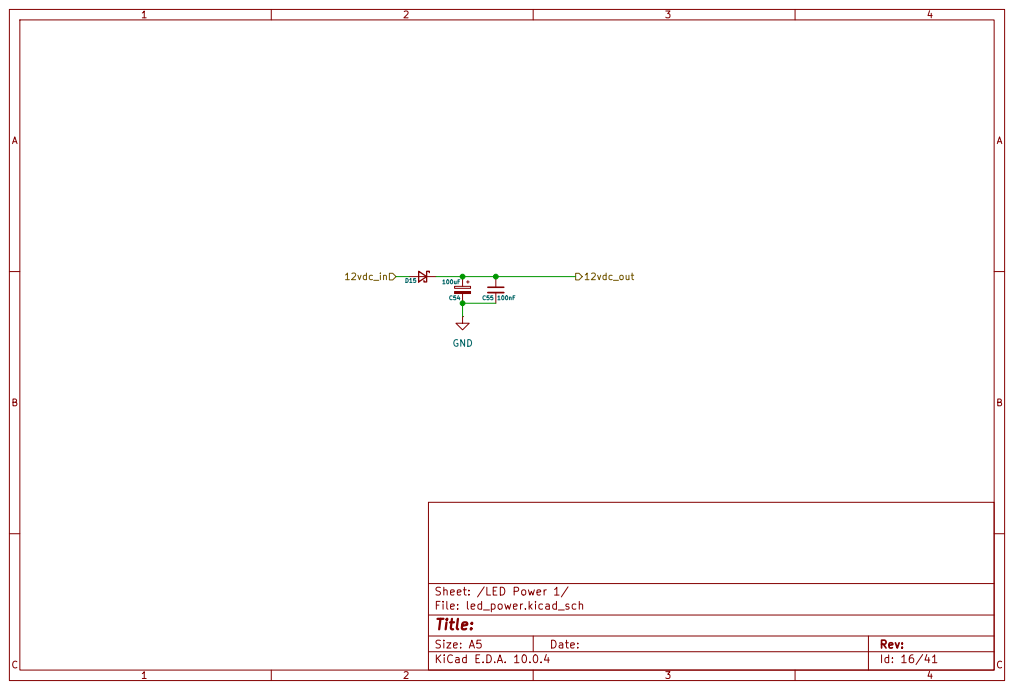
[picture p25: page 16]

Size: A5 | Rev: | C Date:
KiCad E.D.A. 10.0.4 | Id: 16/41

Size: A5 | Rev: | C Date:
KiCad E.D.A. 10.0.4 | Id: 17/41

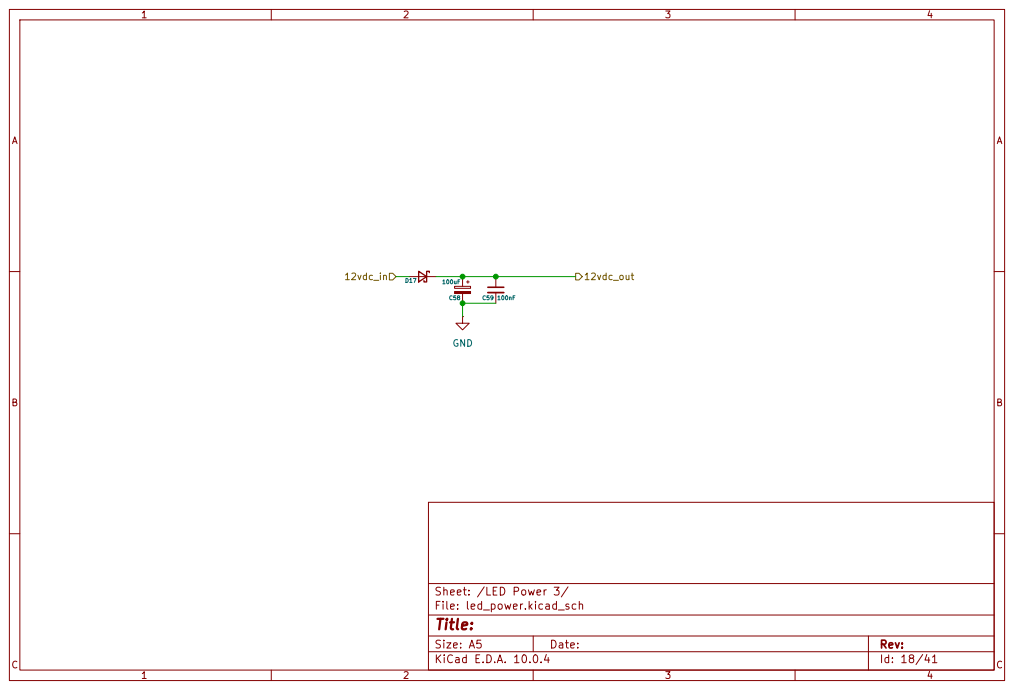
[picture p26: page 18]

Size: A5 | Rev: | C Date:
KiCad E.D.A. 10.0.4 | Id: 18/41

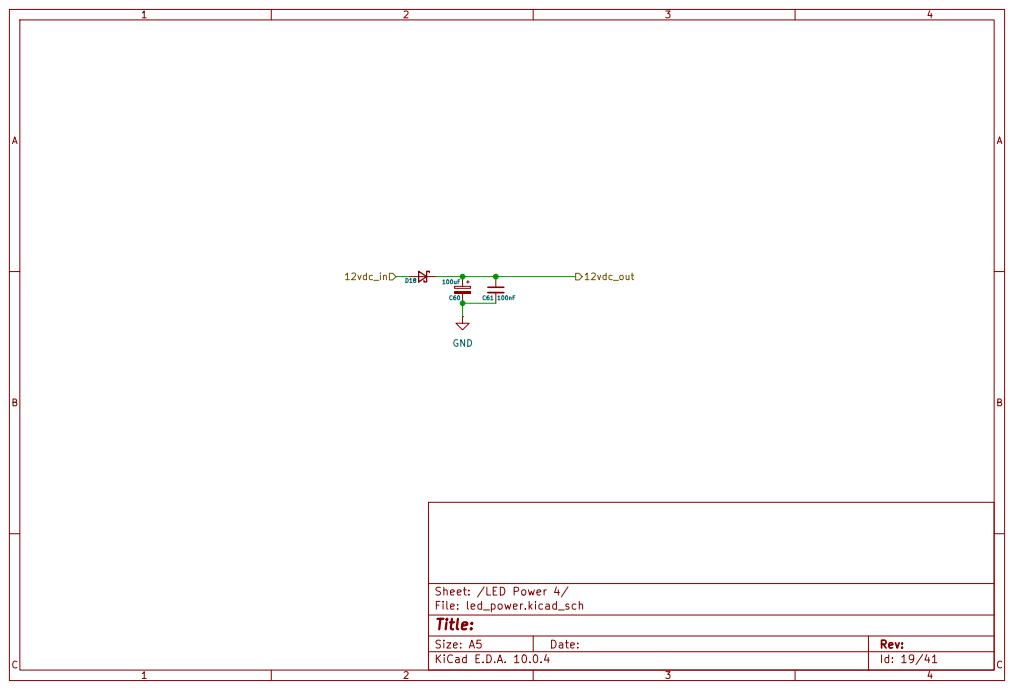
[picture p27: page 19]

Size: A5 | Rev: | C Date:
KiCad E.D.A. 10.0.4 | Id: 19/41

Size: A5 | Rev: | C Date:
KiCad E.D.A. 10.0.4 | Id: 20/41


Size: A5 | Rev: | C Date:
KiCad E.D.A. 10.0.4 | Id: 21/41

Size: A5 | Rev: | C Date:
KiCad E.D.A. 10.0.4 | Id: 23/41


Size: A5 | Rev: | C Date:
KiCad E.D.A. 10.0.4 | Id: 24/41

Size: A5 | Rev: | C Date:
KiCad E.D.A. 10.0.4 | Id: 25/41


Size: A5 | Rev: | C Date:
KiCad E.D.A. 10.0.4 | Id: 26/41


Size: A5 | Rev: | C Date:
KiCad E.D.A. 10.0.4 | Id: 27/41

Size: A5 | Rev: | C Date:
KiCad E.D.A. 10.0.4 | Id: 28/41


Size: A5 | Rev: | C Date:
KiCad E.D.A. 10.0.4 | Id: 29/41

Size: A5 | Rev: | C Date:
KiCad E.D.A. 10.0.4 | Id: 30/41


Size: A5 | Rev: | C Date:
KiCad E.D.A. 10.0.4 | Id: 31/41

Size: A5 | Rev: | C Date:
KiCad E.D.A. 10.0.4 | Id: 32/41


Size: A5 | Rev: | C Date:
KiCad E.D.A. 10.0.4 | Id: 33/41

Size: A5 | Rev: | C Date:
KiCad E.D.A. 10.0.4 | Id: 34/41


Size: A5 | Rev: | C Date:
KiCad E.D.A. 10.0.4 | Id: 35/41


Size: A5 | Rev: | C Date:
KiCad E.D.A. 10.0.4 | Id: 36/41

Size: A4 | Rev:
KiCad E.D.A. 10.0.4 | Id: 37/41


Size: A4 | Rev:
KiCad E.D.A. 10.0.4 | Id: 38/41

Capacitor needs to be positioned

Size: A5 | Rev: | C Date:
KiCad E.D.A. 10.0.4 | Id: 39/41


Capacitor needs to be positioned

Size: A5 | Rev: | C Date:
KiCad E.D.A. 10.0.4 | Id: 40/41

Capacitor needs to be positioned

Size: A5 | Rev: | C Date:
KiCad E.D.A. 10.0.4 | Id: 41/41


Capacitor needs to be positioned
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

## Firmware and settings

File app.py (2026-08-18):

"""SCCS — Flask + SocketIO bridge for lighting/relay control."""

from __future__ import annotations

import atexit
import logging
import os
import subprocess
import sys
import threading
from datetime import datetime
from urllib.parse import urlparse

from flask import Flask, Response, jsonify, render_template, request
from flask_cors import CORS
from flask_socketio import SocketIO, emit

from bridge.runtime import SCCSRuntime
from gps import get_gps_status, set_gps_module
from modules.config import config
from modules.gps import GPSModule
from modules.logger import setup_logging
from modules.phases import PhaseManager
from modules.sensors import SensorManager
from modules.toasts import ToastManager
from modules.ui_state import ConfigManager

import modules.toasts
from network import build_network_status
from sonos import get_sonos_status, set_muted, set_sonos_manager, set_transport, set_volume
from system import get_system_status, set_gps_module as set_system_gps, set_runtime, set_victron_module
from victron import get_power_status, set_victron_manager as set_power_victron
from weather import get_weather_status, set_gps_module as set_weather_gps
from wifi import (
    connect_wifi,
    disconnect_wifi,
    get_wifi_status,
    scan_wifi_networks,
    set_preferred_uplink,
)
from modules.homekit import HomeKitManager
from modules.matter import MatterManager

logger = setup_logging(config)

if config.getboolean("logging", "suppress_werkzeug", fallback=True):
    logging.getLogger("werkzeug").setLevel(logging.WARNING)
if config.getboolean("logging", "suppress_engineio", fallback=True):
    logging.getLogger("engineio").setLevel(logging.WARNING)
if config.getboolean("logging", "suppress_socketio", fallback=True):
    logging.getLogger("socketio").setLevel(logging.WARNING)


def log_exception(exc_type, exc_value, exc_traceback):
    if issubclass(exc_type, KeyboardInterrupt):
        sys.__excepthook__(exc_type, exc_value, exc_traceback)
        return
    logger.critical("Unhandled exception", exc_info=(exc_type, exc_value, exc_traceback))


sys.excepthook = log_exception


def _patch_engineio_werkzeug_websocket() -> None:
    """Engine.IO hijacks the socket for WebSocket upgrades without calling WSGI start_response.

    Werkzeug then raises AssertionError: write() before start_response when the
    handler returns. Signal a dropped connection instead (same idea as gunicorn's
    StopIteration path in engineio's SimpleWebSocketWSGI).
    """
    from engineio.async_drivers import _websocket_wsgi as wswsgi

    if getattr(wswsgi.SimpleWebSocketWSGI, "_sccs_werkzeug_patch", False):
        return

    _orig_call = wswsgi.SimpleWebSocketWSGI.__call__

    def __call__(self, environ, start_response):
        ret = _orig_call(self, environ, start_response)
        if getattr(getattr(self, "ws", None), "mode", None) == "werkzeug":
            raise ConnectionError("WebSocket connection handled outside WSGI")
        return ret

    wswsgi.SimpleWebSocketWSGI.__call__ = __call__
    wswsgi.SimpleWebSocketWSGI._sccs_werkzeug_patch = True


_patch_engineio_werkzeug_websocket()

app = Flask(__name__)
app.config["SECRET_KEY"] = config.get("system", "secret_key", fallback="sccs-secret")
CORS(app)
socketio = SocketIO(app, cors_allowed_origins="*", async_mode="threading")

debug_mode = config.getboolean("system", "debug", fallback=False)
if debug_mode:
    app.config["TEMPLATES_AUTO_RELOAD"] = True
    app.config["SEND_FILE_MAX_AGE_DEFAULT"] = 0

# Settings-tab diagnostic tools (force phase/reed, GPS simulate, toast test).
development_mode = config.getboolean("system", "development_mode", fallback=False)

toast_manager = ToastManager(config, socketio)
modules.toasts.toast_manager = toast_manager

dark_mode_config = ConfigManager("active_dark_mode.json", {"mode": "dark", "manual": False})
_default_theme = config.get("ui", "default_theme", fallback="neuglass")
if _default_theme == "base":
    _default_theme = "neuglass"
theme_config = ConfigManager("active_theme.json", {"theme": _default_theme})
current_global_theme = theme_config.load()["theme"]

runtime = SCCSRuntime(config, socketio=socketio, dark_mode_config=dark_mode_config)
set_runtime(runtime)

gps_module = None
phase_manager = None
sensor_manager = None
victron_module = None
sonos_module = None
homekit_module = None
matter_module = None
first_state_read_done = False
shutdown_event = threading.Event()
_cleanup_done = False


def _theme_sort_key(item: dict) -> tuple:
    name = item["name"].lower()
    return (0 if name.endswith("morphism") else 1, name)


def _extract_css_friendly_name(filepath: str, fallback: str) -> str:
    try:
        with open(filepath, encoding="utf-8") as handle:
            first = handle.readline().strip()
            if first.startswith("/*") and first.endswith("*/"):
                comment = first[2:-2].strip()
                if comment:
                    return comment
    except OSError:
        pass
    return fallback


def _network_status_payload() -> dict:
    start_time = getattr(app, "_start_time", None)
    return build_network_status(start_time)


def network_status_broadcaster() -> None:
    while not shutdown_event.is_set():
        try:
            socketio.emit("network_update", _network_status_payload())
        except Exception:
            pass
        if shutdown_event.wait(8.5):
            break

NAV_ITEMS = [
    {"id": "home", "label": "Home", "icon": "fa-house"},
    {"id": "lighting", "label": "Lighting", "icon": "fa-lightbulb"},
    {"id": "scenes", "label": "Scenes", "icon": "fa-wand-magic-sparkles"},
    {"id": "system", "label": "System", "icon": "fa-gear"},
]


@app.context_processor
def inject_nav():
    return {
        "nav_items": NAV_ITEMS,
        "development_mode": development_mode,
    }


def _require_development_mode(action: str = "action") -> bool:
    """Gate diagnostic socket/HTTP tools when development_mode is off."""
    if development_mode:
        return True
    logger.warning("Ignored %s — [system] development_mode is false", action)
    return False


@app.route("/")
def index():
    return render_template("index.html", active_page="home")


@app.route("/api/power")
def api_power():
    return jsonify(get_power_status())


@app.route("/api/victron")
def api_victron():
    if victron_module:
        return jsonify(victron_module.get_state())
    return jsonify({"stale": True, "shunt": {"configured": False}, "mppt": {"configured": False}})


@app.route("/api/gps")
def api_gps():
    return jsonify(get_gps_status())


@app.route("/api/system")
def api_system():
    return jsonify(get_system_status())


@app.route("/api/weather")
def api_weather():
    return jsonify(get_weather_status())


@app.route("/api/network")
def api_network():
    return jsonify(_network_status_payload())


@app.route("/api/themes")
def api_get_themes():
    themes, seen = [], set()
    themes_dir = os.path.join(app.static_folder, "css", "themes")
    if os.path.isdir(themes_dir):
        for filename in sorted(os.listdir(themes_dir)):
            if not filename.endswith(".css"):
                continue
            base = filename[:-4]
            if base in seen:
                continue
            seen.add(base)
            path = os.path.join(themes_dir, filename)
            fallback = base.replace("-", " ").replace("_", " ").title()
            themes.append({"file": base, "name": _extract_css_friendly_name(path, fallback)})
    themes.sort(key=_theme_sort_key)
    return jsonify({"themes": themes})


@app.route("/api/current-theme")
def api_get_current_theme():
    return jsonify({"theme": current_global_theme})


@app.route("/api/sonos")
def api_sonos():
    return jsonify(get_sonos_status())


@app.route("/api/sonos/transport", methods=["POST"])
def api_sonos_transport():
    payload = request.get_json(silent=True) or {}
    return jsonify(set_transport(str(payload.get("action", ""))))


@app.route("/api/sonos/volume", methods=["POST"])
def api_sonos_volume():
    payload = request.get_json(silent=True) or {}
    try:
        level = int(payload.get("level", 0))
    except (TypeError, ValueError):
        level = 0
    return jsonify(set_volume(level))


@app.route("/api/sonos/mute", methods=["POST"])
def api_sonos_mute():
    payload = request.get_json(silent=True) or {}
    return jsonify(set_muted(bool(payload.get("muted"))))


@app.route("/sonos-art")
def proxy_sonos_album_art():
    art_url = request.args.get("url")
    if not art_url:
        return "Missing url", 400
    try:
        import requests

        parsed = urlparse(art_url)
        if parsed.port != 1400:
            return "Invalid", 403
        resp = requests.get(art_url, timeout=10, stream=True)
        if resp.status_code != 200:
            return "Failed", resp.status_code
        return Response(
            resp.iter_content(8192),
            content_type=resp.headers.get("content-type", "image/jpeg"),
            headers={"Cache-Control": "public, max-age=7200"},
        )
    except Exception as e:
        logger.warning(f"Sonos art proxy: {e}")
        return "Error", 502


@app.route("/api/wifi")
def api_wifi():
    return jsonify(get_wifi_status())


@app.route("/api/wifi/scan", methods=["POST"])
def api_wifi_scan():
    return jsonify(scan_wifi_networks())


@app.route("/api/wifi/connect", methods=["POST"])
def api_wifi_connect():
    payload = request.get_json(silent=True) or {}
    password = payload.get("password")
    if password is not None:
        password = str(password)
    return jsonify(connect_wifi(str(payload.get("ssid", "")), password))


@app.route("/api/wifi/disconnect", methods=["POST"])
def api_wifi_disconnect():
    return jsonify(disconnect_wifi())


@app.route("/api/wifi/prefer", methods=["POST"])
def api_wifi_prefer():
    payload = request.get_json(silent=True) or {}
    prefer = payload.get("prefer") or payload.get("uplink") or ""
    return jsonify(set_preferred_uplink(str(prefer)))


def _apply_light_change(data, *, source: str = "socket"):
    if not data or "name" not in data:
        logger.warning(f"light_change ignored ({source}) — bad payload: {data!r}")
        return None
    name = data["name"]
    if name not in runtime.compiled.light_names:
        logger.warning(f"light_change ignored ({source}) — unknown light: {name}")
        return None
    try:
        target = max(0, min(100, int(data.get("brightness", 0))))
    except (TypeError, ValueError):
        logger.warning(f"light_change ignored ({source}) — invalid brightness: {data.get('brightness')!r}")
        return None
    mode = data.get("mode", "white") if name in runtime.compiled.rgb_lights else None
    runtime.set_light_intent(name, target, mode)
    return runtime.get_ui_state()


@app.route("/api/light", methods=["POST"])
def api_light_change():
    state = _apply_light_change(request.get_json(silent=True) or {}, source="http")
    if state is None:
        return jsonify({"ok": False}), 400
    return jsonify({"ok": True, "state": state})


@app.route("/api/relay", methods=["POST"])
def api_relay_change():
    data = request.get_json(silent=True) or {}
    name = data.get("name")
    if name not in runtime.compiled.relay_names:
        logger.warning(f"relay_change ignored (http) — unknown relay: {name}")
        return jsonify({"ok": False}), 400
    runtime.set_relay_intent(name, bool(data.get("on", False)))
    return jsonify({"ok": True})


@app.route("/api/explain")
def api_explain():
    return jsonify(runtime.get_explain_json())


@app.route("/api/scenes")
def api_get_scenes():
    scenes = dict(
        sorted(runtime.compiled.scenes.items(), key=lambda item: item[1].get("order", 999))
    )
    return jsonify({
        "scenes": [
            {
                "key": k,
                "name": d["name"],
                "icon": d["icon"],
                "description": d["description"],
                "all_off": d["all_off"],
            }
            for k, d in scenes.items()
        ]
    })


@app.route("/api/scene", methods=["POST"])
def api_set_scene():
    data = request.get_json(silent=True) or {}
    scene = data.get("scene")
    if not scene or scene not in runtime.compiled.scenes:
        return jsonify({"ok": False}), 400
    runtime.set_scene(scene)
    return jsonify({
        "ok": True,
        "state": runtime.get_ui_state(),
        "ramp_ms": runtime.compiled.scene_ramp_ms,
    })


@app.route("/api/lights")
def api_get_lights():
    return jsonify({
        "lights": runtime.get_frontend_config(),
        "state": runtime.get_ui_state(),
    })


@app.route("/api/reeds/force", methods=["POST"])
def api_force_reed():
    if not _require_development_mode("force_reed"):
        return jsonify({"ok": False, "error": "development_mode required"}), 403
    data = request.get_json(silent=True) or {}
    name = data.get("name")
    if name is None:
        return jsonify({"ok": False, "error": "name required"}), 400
    state = runtime.force_reed(name, data.get("closed"))
    return jsonify({
        "ok": True,
        "state": state,
        "ramp_ms": state.get("_ramp_ms") or runtime.compiled.reed_ramp_ms,
        "reeds": runtime.get_reed_diag_json(),
        "effective": runtime.effective_reed_states(),
    })


@app.route("/api/reeds")
def api_get_reeds():
    diag = runtime.get_reed_diag_json()
    return jsonify({
        "reeds": runtime.get_reeds_frontend_config(),
        "states": runtime.effective_reed_states(),
        "raw": diag.get("states", {}),
        "forced": diag.get("forced", {}),
    })


def _screen_frontend_item(name: str, conf: dict, conn: dict | None = None) -> dict:
    """Build one screen record for the system tile."""
    from actuators.screens import brightness_is_adjustable

    observed_pct = 0
    if runtime.screen_actuator:
        observed_pct = runtime.screen_actuator._observed.get(name, 0)

    adjustable = brightness_is_adjustable(conf.get("brightness_path") or "")

    item = {
        "name": name,
        "label": conf.get("friendly", name),
        "icon": conf.get("icon", "fa-display"),
        "online": False,
        "latency": None,
        "on": observed_pct > 0,
        "brightness": None,
        "brightness_pct": observed_pct if observed_pct > 0 else None,
        "brightness_adjustable": adjustable,
        "ssh_passwordless": False,
        "ssh_error": None,
    }
    if conn:
        if conn.get("on") is not None:
            item["on"] = conn["on"]
        item["online"] = conn.get("online", False)
        item["brightness"] = conn.get("brightness")
        if conn.get("brightness_pct") is not None:
            item["brightness_pct"] = conn["brightness_pct"]
        item["ssh_passwordless"] = conn.get("ssh_passwordless", False)
        item["ssh_error"] = conn.get("ssh_error")
    return item


def _screens_list(*, probe: bool = False) -> list:
    if not runtime.screen_actuator:
        return []
    screens = []
    for name, conf in runtime.compiled.screens.items():
        conn = None
        if probe:
            conn = runtime.screen_actuator.test_connectivity(name)
        screens.append(_screen_frontend_item(name, conf, conn))
    return screens


@app.route("/api/screens")
def api_get_screens():
    return jsonify({"screens": _screens_list()})


@app.route("/api/screens/status")
def api_get_screens_status():
    return jsonify({"screens": _screens_list(probe=True)})


def _cleanup_best_effort(timeout_s: float = 10) -> None:
    """Run cleanup without blocking shutdown if hardware teardown hangs."""
    try:
        worker = threading.Thread(target=cleanup, daemon=True, name="shutdown-cleanup")
        worker.start()
        worker.join(timeout=timeout_s)
        if worker.is_alive():
            logger.warning("Shutdown cleanup did not finish within %.0fs", timeout_s)
    except Exception as e:
        logger.error(f"Shutdown cleanup error: {e}")


def _issue_host_shutdown() -> bool:
    """Schedule host power-off. Never call this in tests without mocking."""
    try:
        subprocess.Popen(
            ["sudo", "-n", "shutdown", "-h", "now"],
            stdout=subprocess.DEVNULL,
            stderr=subprocess.DEVNULL,
            start_new_session=True,
        )
        logger.warning("Host shutdown command issued")
        return True
    except Exception as e:
        logger.error(f"Host shutdown failed: {e}")
        return False


@app.route("/api/system/shutdown", methods=["POST"])
def api_system_shutdown():
    """Shut down remote touchscreens, then this Pi."""
    logger.warning("System shutdown requested via API")

    def _shutdown_sequence():
        import time

        # Screens first: host power-off tears down the network and kills SSH.
        # shutdown_all() blocks until each remote attempt finishes (or times out).
        if runtime.screen_actuator:
            try:
                runtime.screen_actuator.shutdown_all()
            except Exception as e:
                logger.warning("Screen shutdown phase failed: %s", e)

        # Issue host shutdown before cleanup — GPIO factory.close() can hang
        # indefinitely and previously prevented shutdown from ever running.
        if not _issue_host_shutdown():
            return

        time.sleep(2)
        _cleanup_best_effort()

    threading.Thread(target=_shutdown_sequence, daemon=True, name="shutdown-host").start()
    return jsonify({"ok": True, "message": "Shutting down…"})


@app.route("/api/phases")
def api_get_phases():
    if not phase_manager:
        return jsonify({"phase": None, "forced": False, "times": {}, "settings": {}})
    times = {}
    settings = {}
    try:
        times = phase_manager.get_phase_times()
    except Exception:
        pass
    try:
        settings = phase_manager.get_timing_settings()
    except Exception:
        pass
    return jsonify({
        "phase": phase_manager.get_phase(),
        "forced": phase_manager.is_forced(),
        "times": times,
        "settings": settings,
    })


@app.route("/api/phases/timing", methods=["POST"])
def api_set_phase_timing():
    """Update [phases] day/evening offsets and night start hour."""
    if not phase_manager:
        return jsonify({"ok": False, "error": "Phase manager unavailable"}), 503

    data = request.get_json(silent=True) or {}
    kwargs = {}
    if "day_offset_minutes" in data:
        kwargs["day_offset_minutes"] = data.get("day_offset_minutes")
    if "evening_offset_minutes" in data:
        kwargs["evening_offset_minutes"] = data.get("evening_offset_minutes")
    if "night_start_minutes" in data:
        kwargs["night_start_minutes"] = data.get("night_start_minutes")
    elif "night_start_hour" in data:
        # Legacy hour-only clients.
        kwargs["night_start_hour"] = data.get("night_start_hour")

    if not kwargs:
        return jsonify({"ok": False, "error": "No timing fields provided"}), 400

    try:
        result = phase_manager.update_timing_settings(**kwargs)
    except ValueError as exc:
        return jsonify({"ok": False, "error": str(exc)}), 400
    except Exception as exc:
        logger.error("Phase timing update failed: %s", exc)
        return jsonify({"ok": False, "error": "Failed to update phase timing"}), 500

    return jsonify({"ok": True, "message": "Phase timing saved", **result})


def _ensure_homekit_manager():
    global homekit_module
    if homekit_module is None:
        homekit_module = HomeKitManager(runtime, config, socketio=socketio)
    return homekit_module


def _ensure_matter_manager():
    global matter_module
    if matter_module is None:
        matter_module = MatterManager(runtime, config, socketio=socketio)
    return matter_module


@app.route("/api/matter")
def api_matter_status():
    if not matter_module:
        enabled = bool(config.getboolean("matter", "enabled", fallback=False))
        return jsonify({
            "ok": True,
            "enabled": enabled,
            "running": False,
            "paired": False,
            "error": None,
        })
    return jsonify(matter_module.status())


@app.route("/api/matter", methods=["POST"])
def api_matter_update():
    data = request.get_json(silent=True) or {}
    if "enabled" not in data:
        return jsonify({"ok": False, "error": "enabled required"}), 400
    mgr = _ensure_matter_manager()
    return jsonify(mgr.set_enabled(bool(data.get("enabled"))))


@app.route("/api/matter/reset", methods=["POST"])
def api_matter_reset():
    mgr = _ensure_matter_manager()
    result = mgr.reset_pairing()
    if result.get("ok") is False:
        return jsonify(result), 500
    result["ok"] = True
    return jsonify(result)


@app.route("/api/homekit")
def api_homekit_status():
    if not homekit_module:
        enabled = bool(config.getboolean("homekit", "enabled", fallback=False))
        return jsonify({
            "ok": True,
            "enabled": enabled,
            "running": False,
            "paired": False,
            "error": None,
        })
    return jsonify(homekit_module.status())


@app.route("/api/homekit", methods=["POST"])
def api_homekit_update():
    data = request.get_json(silent=True) or {}
    if "enabled" not in data:
        return jsonify({"ok": False, "error": "enabled required"}), 400
    mgr = _ensure_homekit_manager()
    return jsonify(mgr.set_enabled(bool(data.get("enabled"))))


@app.route("/api/homekit/reset", methods=["POST"])
def api_homekit_reset():
    mgr = _ensure_homekit_manager()
    result = mgr.reset_pairing()
    if result.get("ok") is False:
        return jsonify(result), 500
    result["ok"] = True
    return jsonify(result)
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

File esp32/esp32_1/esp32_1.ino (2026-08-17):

/*
 * SCCS — ESP32-1 (ESP32-S3-WROOM-1U)
 *
 * Pi link: Pi GPIO 4 (TX) / 5 (RX) ↔ this ESP UART0 GPIO 44 (RX) / 43 (TX).
 *
 * PWM (module GPIO): 4–11  (silk 1-4 … 1-11)
 *   1-4 kitchen panel white, 1-5 red, 1-6 green
 *   1-7 kitchen bench, 1-8 storage, 1-9 rear drawer
 *   1-10 / 1-11 spare
 * Analog: GPIO 1 (silk 1-1) water tank sender (150 Ω to 3V3)
 *
 * Module: ESP32-S3-WROOM-1U. Upload: see esp32/README.md
 */

#define SCCS_ESP_ID 1
#define SCCS_PWM_PINS {4, 5, 6, 7, 8, 9, 10, 11}
#define SCCS_ANALOG_PINS {1}

// Host UART0 to the Pi (same pins as the ROM bootloader).
#define SCCS_HOST_RX 44
#define SCCS_HOST_TX 43

#include "SccsEspFirmware.h"

void setup() {
  sccsSetup();
}

void loop() {
  sccsLoop();
}

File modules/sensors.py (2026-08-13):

# modules/sensors.py
import threading
import time
import logging
import glob
import os
import struct
import subprocess

logger = logging.getLogger("sccs")
logger.propagate = True

W1_DEVICES_DIR = "/sys/bus/w1/devices/"
W1_DT_BASE = "/sys/firmware/devicetree/base"


class SensorManager:
    def __init__(self, config, send_command_func, socketio):
        self.config = config
        self.send_command = send_command_func
        self.socketio = socketio
        self.running = False
        self.thread = None
        self.on_update = None

        # Load 1-Wire kernel modules (best effort). On modern Raspberry Pi OS these
        # are usually loaded automatically by dtoverlay=w1-gpio in config.txt.
        # Running as non-root user will cause "Operation not permitted", which is harmless.
        try:
            subprocess.run(['modprobe', 'w1-gpio'], capture_output=True, check=False)
            subprocess.run(['modprobe', 'w1-therm'], capture_output=True, check=False)
        except Exception:
            pass
        time.sleep(0.5)

        # ====================== CALIBRATION FROM CONFIG ======================
        # Divider: 3V3 -- R_pullup (150 Ω) -- sense -- R_sender -- GND
        # Sender: empty ≈ 240 Ω, full ≈ 33 Ω (standard automotive fuel sender).
        self.WATER_R_EMPTY = config.getfloat('sensors', 'water_resistance_empty', fallback=240.0)
        self.WATER_R_FULL = config.getfloat('sensors', 'water_resistance_full', fallback=33.0)
        self.WATER_R_PULLUP = config.getfloat('sensors', 'water_pullup_ohms', fallback=150.0)
        # ESP32-S3 ADC is 12-bit (0..4095) unless firmware remaps to 10-bit.
        self.WATER_ADC_MAX = config.getfloat('sensors', 'water_adc_max', fallback=4095.0)
        self.WATER_CAPACITY_LITRES = config.getfloat('tanks', 'water_litres', fallback=0)

        # Water level on ESP32-1 module GPIO (silk 1-1); ANALOG <gpio> protocol.
        self.WATER_PIN = config.getint('esp32 analog', 'water_pin')
        self.WATER_ESP = config.getint('esp32 analog', 'water_esp', fallback=1)

        # Dual 1-Wire buses (SCCS PCB): GPIO4 outside+fridge, GPIO3 freezer.
        # Must match dtoverlay=w1-gpio,gpiopin=N lines in /boot/firmware/config.txt.
        self.OUTSIDE_BUS_GPIO = config.getint('sensors', 'outside_temp_bus_gpio', fallback=4)
        self.FRIDGE_BUS_GPIO = config.getint('sensors', 'fridge_temp_bus_gpio', fallback=4)
        self.FREEZER_BUS_GPIO = config.getint('sensors', 'freezer_temp_bus_gpio', fallback=3)

        # 1-Wire DS18B20 sensor IDs (folder names under /sys/bus/w1/devices/, e.g. "28-3ce1d4435d5a")
        # Leave blank to auto-detect first available 28* device on that role's bus.
        self.OUTSIDE_TEMP_ID = (config.get('sensors', 'outside_temp_sensor', fallback='') or '').strip() or None
        self.FRIDGE_TEMP_ID = (config.get('sensors', 'fridge_temp_sensor', fallback='') or '').strip() or None
        self.FREEZER_TEMP_ID = (config.get('sensors', 'freezer_temp_sensor', fallback='') or '').strip() or None
        # ========================================================

        self._last_analog_warn = 0.0
        self._last_vcc_warn = 0.0
        self._last_missing_warn: dict[str, float] = {}
        self.last_reading: dict = {}

        # gpio_pin -> sysfs master path (e.g. /sys/devices/w1_bus_master1)
        self._w1_masters_by_gpio = self._discover_w1_masters_by_gpio()
        expected_gpios = sorted({self.OUTSIDE_BUS_GPIO, self.FRIDGE_BUS_GPIO, self.FREEZER_BUS_GPIO})
        found = sorted(self._w1_masters_by_gpio.keys())
        logger.info(
            "🔋 1-Wire buses: expected GPIO %s → masters on GPIO %s",
            expected_gpios,
            found if found else "none yet",
        )
        for gpio in expected_gpios:
            if gpio not in self._w1_masters_by_gpio:
                logger.warning(
                    "   🌡️ No w1 master for GPIO %s — add "
                    "dtoverlay=w1-gpio,gpiopin=%s to /boot/firmware/config.txt and reboot",
                    gpio,
                    gpio,
                )

        configured = []
        if self.OUTSIDE_TEMP_ID:
            configured.append(f"outside={self.OUTSIDE_TEMP_ID}@GPIO{self.OUTSIDE_BUS_GPIO}")
        else:
            configured.append(f"outside=auto@GPIO{self.OUTSIDE_BUS_GPIO}")
        if self.FRIDGE_TEMP_ID:
            configured.append(f"fridge={self.FRIDGE_TEMP_ID}@GPIO{self.FRIDGE_BUS_GPIO}")
        else:
            configured.append(f"fridge=none@GPIO{self.FRIDGE_BUS_GPIO}")
        if self.FREEZER_TEMP_ID:
            configured.append(f"freezer={self.FREEZER_TEMP_ID}@GPIO{self.FREEZER_BUS_GPIO}")
        else:
            configured.append(f"freezer=none@GPIO{self.FREEZER_BUS_GPIO}")
        logger.info("🔋 1-Wire temp sensors configured: %s", ", ".join(configured))

        logger.info("🔋 SensorManager initialized")

    @staticmethod
    def _discover_w1_masters_by_gpio() -> dict[int, str]:
        """Map each w1-gpio overlay pin to its sysfs master directory.

        Raspberry Pi device-tree nodes look like /proc/device-tree/onewire@N
        with a 3-cell `gpios` property: <phandle pin flags>. Platform devices
        expose of_node → those DT nodes, and w1 registers them as w1_bus_master*.
        """
        gpio_to_dt: dict[int, str] = {}
        if os.path.isdir(W1_DT_BASE):
            try:
                for name in os.listdir(W1_DT_BASE):
                    if not name.startswith("onewire"):
                        continue
                    gpios_path = os.path.join(W1_DT_BASE, name, "gpios")
                    if not os.path.isfile(gpios_path):
                        continue
                    try:
                        with open(gpios_path, "rb") as fh:
                            data = fh.read()
                        if len(data) >= 12:
                            pin = struct.unpack(">I", data[4:8])[0]
                            gpio_to_dt[pin] = os.path.realpath(os.path.join(W1_DT_BASE, name))
                    except OSError:
                        continue
            except OSError:
                pass

        masters: dict[int, str] = {}
        for master in sorted(glob.glob("/sys/devices/w1_bus_master*")):
            of_node = os.path.join(master, "of_node")
            if not os.path.exists(of_node):
                continue
            try:
                real = os.path.realpath(of_node)
            except OSError:
                continue
            for gpio, dt_path in gpio_to_dt.items():
                if real == dt_path or real.endswith(os.path.basename(dt_path)):
                    masters[gpio] = master
                    break
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

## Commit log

2026-08-17 Fixed ESP32 flashing procedure
    [SccsEspFirmware.h, esp32.py, esp32_1.ino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]
2026-08-18 Updated Kicad schematics
    [1_wire_bus.kicad_sch, SCCS-RPI.kicad_sch, analog_inputs.kicad_sch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]
2026-08-18 Added installer option to delete temp sensor from config
